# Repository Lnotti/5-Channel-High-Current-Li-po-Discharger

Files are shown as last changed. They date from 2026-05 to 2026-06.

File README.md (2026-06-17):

# 5 Channel High Current LiPo Storage Discharger

A PCB designed to discharge 6S LiHV battery packs to storage voltage (3.8V per cell / 22.8V total) across up to 5 independent channels simultaneously.

## Overview

Leaving LiPo packs fully charged for extended periods degrades cell chemistry over time. This board solves that by providing a dedicated, controlled way to bring packs down to storage voltage after a flying session without needing a full featured charger to do it.

Each of the 5 channels accepts a 6S pack via an XT60 connector and independently discharges it to 22.8V, cutting off automatically when the target is reached. Channels are fully isolated from each other so packs at different voltages can be discharged simultaneously without risk.

## Problems with current solutions

I have a lipo charger that doubles as a lipo discharger, but it falls short in many aspects.
- Cost ($100+)
- Only two channels
- Discharge current only 0.2A max
- Slows down immensely close to the end of discharge cycle

I also have small lipo discharger that clip onto individual packs that also fall short
- Takes 3+ hours to discharge to storage
- Only has a light to let me know that it has finished (I forget about them since they are so small)
- High leakage current
- High leakage current combined with the time taken to discharge combined with their forgettability leads to frequent overdischarging making me plug them back in to charge ruining the ease

## Status

Version 0.1.1 is a complete board redesign addressing multiple hardware issues identified during review of the 0.1.0 prototype. The revised board has been submitted for manufacture. Testing and firmware development are ongoing.

## Hardware

- STM32F103C8T6 microcontroller
- Active MOSFET load per channel with wirewound power resistors
- Buck converter and 3.3V LDO onboard power supply
- USB-C port for firmware flashing via DFU bootloader
- Active cooling via 40mm 5V fan
- Power status LED for supply rail debugging
- SWD header for live debugging
- Multiple STM32 connectivity options: USB, I2C, ST-Link, UART, DFU

## Specifications

- Input: 6S LiHV (22.8V - 26.1V)
- Channels: 5 independent
- Discharge current: approximately 1A per channel
- Target storage voltage: 22.8V (3.8V per cell)
- Connector: XT60 female PCB mount
- Board dimensions: 160 x 110mm

## Version History

### v0.1.1 — Complete Board Redesign
*Current version*

A full redesign addressing hardware errors found during schematic and layout review of v0.1.0.

**Bug fixes:**
- Corrected footprints for large wirewound power resistors which were wrong in v0.1.0
- Fixed STM32F103C8T6 footprint which was incorrect in v0.1.0
- Replaced buck converter with a higher rated part after identifying that the original selection would be insufficient for LiHV pack voltages (26.1V max vs 25.2V assumed for standard LiPo)
- Updated voltage divider resistor values (1M / 120k) to bring the ADC sense voltage within safe range for LiHV full charge voltage — previous values would have exceeded the STM32 3.3V ADC input limit at 26.1V
- Updated voltage dividers to higher values to reduce current draw, as to not discharge batteries less than their storage voltage after discharging process is complete.

**Design changes:**
- Discharge resistors repositioned to the center of the board based on thermal simulation results for improved heat distribution
- Removed per-channel RGB LEDs to simplify bring-up and reduce scope; power system debugging is now the immediate priority
- Added power rail status LED to aid debugging of the onboard supply
- Added multiple STM32 connectivity options: USB, I2C, ST-Link, UART, DFU headers
- Removed oversized battery net traces; 1A continuous current does not require large copper pours
- Redesigned discharge channels using hierarchical sheets for layout uniformity across all 5 channels and easier future edits
- General board layout cleanup and component alignment

**Known limitations:**
- RGB per-channel status LEDs removed; may be reintroduced in a later revision once core functionality is validated
- Unsure of how precise the mosfet discharge current in relation to gate voltage will be, this may create issues with precision at the end of a discharge cycle limiting speed.
- Firmware development not yet started
- Unsure of what control loop I will use to handle getting to storage voltage at a consistent current with no overshoot

---

### v0.1.0 — Initial Prototype
*First PCB submission. Multiple hardware errors identified prior to and during bring-up.*

- Initial 5-channel discharge board design
- STM32F103C8T6 microcontroller
- PCA9685 16 channel PWM driver for RGB status LEDs
- Per channel RGB status LED
- USB-C DFU bootloader
- SWD debug header
- 160 x 110mm board

**Issues identified:**
- Wrong footprints for wirewound power resistors
- Wrong STM32 footprint
- Buck converter underrated for LiHV input voltage
- Voltage divider ratio unsafe for LiHV full charge voltage on STM32 ADC
- Board layout not uniform across discharge channels

---

## Planned Revisions

- Case design with integrated fan mounting and ventilation
- Thermal testing and validation on physical hardware
- Firmware development and testing
- Potential reintroduction of per-channel RGB status LEDs
- Potential support for additional cell counts
- Further refinement based on prototype testing results

## Repository Contents

- KiCad schematic and PCB layout files
- Gerber files for manufacture
- Bill of materials

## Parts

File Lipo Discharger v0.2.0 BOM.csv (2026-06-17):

Id | Designator | Footprint | Quantity | Designation | Supplier and ref
1 | C1 | C_0805_2012Metric_Pad1.18x1.45mm_HandSolder | 1 | 10uf 35V
2 | C2, C18, C19, C20, C21, C22 | C_0805_2012Metric_Pad1.18x1.45mm_HandSolder | 6 | 100nF
3 | C3, C4, C6 | C_0805_2012Metric_Pad1.18x1.45mm_HandSolder | 3 | 22µF
4 | C5 | C_0805_2012Metric_Pad1.18x1.45mm_HandSolder | 1 | 10µF
5 | C7 | C_0603_1608Metric | 1 | 10u
6 | C8, C9, C10, C11, C12 | C_0402_1005Metric | 5 | 100n
7 | C13 | C_0402_1005Metric | 1 | 10n
8 | C14, C15 | C_0402_1005Metric | 2 | 1u
9 | C17, C25 | C_0402_1005Metric | 2 | 10p
10 | D1 | D_SMB_Handsoldering | 1 | SS34
11 | D3, D4, D5, D6, D7 | D_SMB_Handsoldering | 5 | SMBJ26A
12 | D13 | D_DO-35_SOD27_P7.62mm_Horizontal | 1 | 1N4148
13 | D14, D15, D16, D17, D18 | D_SMA | 5 | SS34
14 | D19 | LED_2010_5025Metric_Pad1.52x2.65mm_HandSolder | 1 | LED
15 | FAN | PinHeader_1x02_P2.54mm_Vertical | 1 | FAN
16 | FB1 | L_0603_1608Metric | 1 | 120R
17 | I2C, ST-Link, UART | PinHeader_1x04_P2.00mm_Vertical | 3 | Conn_01x04_Male
18 | J2 | USB_C_Receptacle_HRO_TYPE-C-31-M-12 | 1 | USB_C_Receptacle_USB2.0_16P
19 | J4, J5, J6, J7, J8 | AMASS_XT60PW-M_1x02_P7.20mm_Horizontal | 5 | XT60_P1
20 | L1 | L_7.3x7.3_H4.5 | 1 | 4.7µH
21 | Q1, Q2, Q3, Q4, Q5 | TO-220-3_Vertical | 5 | IRLZ44N
22 | Q6 | TO-92_Inline | 1 | 2N2222
23 | R2 | R_0402_1005Metric | 1 | 10k
24 | R3 | R_0402_1005Metric | 1 | 1k5
25 | R4 | R_0805_2012Metric_Pad1.20x1.40mm_HandSolder | 1 | 1K
26 | R8, R14, R20, R26, R32 | R_0805_2012Metric_Pad1.20x1.40mm_HandSolder | 5 | 1M
27 | R9, R15, R21, R27, R33 | R_0805_2012Metric_Pad1.20x1.40mm_HandSolder | 5 | 120k
28 | R10, R17, R23, R29, R35 | R_0805_2012Metric_Pad1.20x1.40mm_HandSolder | 5 | 10
29 | R11, R16, R22, R28, R34 | R_0805_2012Metric_Pad1.20x1.40mm_HandSolder | 5 | 100k
30 | R12, R13, R18, R19, R24, R25, R30, R31, R36, R37, R55, R56, R57, R58, R59 | R_Axial_Power_L38.0mm_W6.4mm_P45.72mm | 15 | 8.2R 10W
31 | R54 | R_0805_2012Metric_Pad1.20x1.40mm_HandSolder | 1 | 100
32 | RP_SCL1, RP_SDA1 | R_0402_1005Metric | 2 | 2k2
33 | SW1 | SW_PUSH_6mm | 1 | SW_Push
34 | U1 | TSOT-23-6 | 1 | AP63205WU-7
35 | U2 | SOT-223-3_TabPin2 | 1 | AMS1117-3.3
36 | U3 | LQFP-48_7x7mm_P0.5mm | 1 | STM32F103C8T6
37 | Y1 | Crystal_SMD_3225-4Pin_3.2x2.5mm | 1 | 16MHz

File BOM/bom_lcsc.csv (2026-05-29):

Id | Designator | Footprint | Quantity | Designation
1 | C1 | C_0805_2012Metric | 1 | 10uF 35V
2 | C2,C7,C8,C9,C10,C11,C12,C15,C18,C19,C20,C21,C22,C23 | C_0805_2012Metric | 14 | 100nF
3 | C3,C4 | C_0805_2012Metric | 2 | 22uF 10V
4 | C5,C6 | C_0805_2012Metric | 2 | 10uF
5 | C13 | C_0805_2012Metric | 1 | 1uF
6 | C14 | C_0805_2012Metric | 1 | 10nF
7 | C16,C17 | C_0805_2012Metric | 2 | 20pF
8 | D1 | D_SMB | 1 | SMBJ26A
9 | D2 | D_SMB | 1 | SS34
10 | D3,D5,D7,D9,D11 | D_SMB | 5 | SMBJ26A
11 | D4,D6,D8,D10,D12 | LED_D5.0mm_RGB | 5 | RGB LED Common Cathode 5mm
12 | D13 | D_DO-35 | 1 | 1N4148
13 | D14,D15,D16,D17,D18 | D_SMA | 5 | SS34
14 | F1 | Fuse_1206 | 1 | Polyfuse 500mA
15 | J2 | USB_C_Receptacle | 1 | USB-C Receptacle 16P
16 | J3 | PinHeader_1x04_P2.54mm | 1 | Pin Header 1x4 2.54mm
17 | J4,J5,J6,J7,J8 | AMASS_XT60-F | 5 | XT60 Female PCB Mount
18 | J9 | PinHeader_1x02_P2.54mm | 1 | Pin Header 1x2 2.54mm
19 | L1 | L_Bourns_SRR1260 | 1 | 22uH SRR1260
20 | Q1,Q2,Q3,Q4,Q5 | TO-220-3 | 5 | IRLZ44NPBF
21 | Q6 | TO-92 | 1 | 2N2222
22 | R1,R8,R11,R14,R16,R20,R22,R26,R28,R32,R34 | R_0805 | 11 | 100k 1%
23 | R2 | R_0805 | 1 | 20k 1%
24 | R3,R4,R48 | R_0805 | 3 | 10k
25 | R5 | R_0805 | 1 | 1M
26 | R6,R7 | R_0805 | 2 | 5.1k
27 | R9,R15,R21,R27,R33 | R_0805 | 5 | 15k 1%
28 | R10,R17,R23,R29,R35 | R_0805 | 5 | 10R
29 | R12,R13,R18,R19,R24,R25,R30,R31,R36,R37,R55,R56,R57,R58,R59 | R_Axial_Power | 15 | 8.2R 10W
30 | R38,R41,R44,R47,R51 | R_0805 | 5 | 68R
31 | R39,R40,R42,R43,R45,R46,R49,R50,R52,R53 | R_0805 | 10 | 22R
32 | R54 | R_0805 | 1 | 100R
33 | SW1 | SW_PUSH_6mm | 1 | Tactile Switch 6mm
34 | U1 | TSOT-23-6 | 1 | MP2359DJ-LF-Z
35 | U2 | SOT-223-3 | 1 | AMS1117-3.3
36 | U3 | LQFP-48 | 1 | STM32F103C8T6
37 | U4 | QFN-28 | 1 | PCA9685BS
38 | Y1 | Crystal_SMD_3225-4Pin | 1 | 8MHz Crystal

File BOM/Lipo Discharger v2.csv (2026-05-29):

Id | Designator | Footprint | Quantity | Designation | Supplier and ref
1 | C1 | C_0805_2012Metric_Pad1.18x1.45mm_HandSolder | 1 | 10uf 35V
2 | C2, C7, C8, C9, C10, C11, C12, C15, C18, C19, C20, C21, C22, C23 | C_0805_2012Metric_Pad1.18x1.45mm_HandSolder | 14 | 100nF
3 | C3, C4 | C_0805_2012Metric_Pad1.18x1.45mm_HandSolder | 2 | 22uF 10V
4 | C5, C6 | C_0805_2012Metric_Pad1.18x1.45mm_HandSolder | 2 | 10uF
5 | C13 | C_0805_2012Metric_Pad1.18x1.45mm_HandSolder | 1 | 1uF
6 | C14 | C_0805_2012Metric_Pad1.18x1.45mm_HandSolder | 1 | 10nF
7 | C16, C17 | C_0805_2012Metric_Pad1.18x1.45mm_HandSolder | 2 | 20pF
8 | D1 | D_SMB_Handsoldering | 1 | D_TVS
9 | D2 | D_SMB_Handsoldering | 1 | SS34
10 | D3, D5, D7, D9, D11 | D_SMB_Handsoldering | 5 | SMBJ26A
11 | D4, D6, D8, D10, D12 | LED_D5.0mm-4_RGB | 5 | LED_KRGB
12 | D13 | D_DO-35_SOD27_P7.62mm_Horizontal | 1 | 1N4148
13 | D14, D15, D16, D17, D18 | D_SMA | 5 | SS34
14 | F1 | Fuse_1206_3216Metric_Pad1.42x1.75mm_HandSolder | 1 | Polyfuse
15 | J2 | USB_C_Receptacle_HRO_TYPE-C-31-M-12 | 1 | USB_C_Receptacle_USB2.0_16P
16 | J3 | PinHeader_1x04_P2.54mm_Vertical | 1 | SWD
17 | J4 | AMASS_XT60-F_1x02_P7.20mm_Vertical | 1 | XT60_P1
18 | J5 | AMASS_XT60-F_1x02_P7.20mm_Vertical | 1 | XT60_P2
19 | J6 | AMASS_XT60-F_1x02_P7.20mm_Vertical | 1 | XT60_P3
20 | J7 | AMASS_XT60-F_1x02_P7.20mm_Vertical | 1 | XT60_P4
21 | J8 | AMASS_XT60-F_1x02_P7.20mm_Vertical | 1 | XT60_P5
22 | J9 | PinHeader_1x02_P2.54mm_Vertical | 1 | FAN
23 | L1 | L_Bourns_SRR1260 | 1 | 22uH
24 | Q1, Q2, Q3, Q4, Q5 | TO-220-3_Vertical | 5 | IRLZ44N
25 | Q6 | TO-92_Inline | 1 | 2N2222
26 | R1, R8, R11, R14, R16, R20, R22, R26, R28, R32, R34 | R_0805_2012Metric_Pad1.20x1.40mm_HandSolder | 11 | 100k
27 | R2 | R_0805_2012Metric_Pad1.20x1.40mm_HandSolder | 1 | 20k
28 | R3, R4, R48 | R_0805_2012Metric_Pad1.20x1.40mm_HandSolder | 3 | 10k
29 | R5 | R_0805_2012Metric_Pad1.20x1.40mm_HandSolder | 1 | 1M
30 | R6, R7 | R_0805_2012Metric_Pad1.20x1.40mm_HandSolder | 2 | 5.1k
31 | R9, R15, R21, R27, R33 | R_0805_2012Metric_Pad1.20x1.40mm_HandSolder | 5 | 15k
32 | R10, R17, R23, R29, R35 | R_0805_2012Metric_Pad1.20x1.40mm_HandSolder | 5 | 10
33 | R12, R13, R18, R19, R24, R25, R30, R31, R36, R37, R55, R56, R57, R58, R59 | R_Axial_Power_L25.0mm_W9.0mm_P27.94mm | 15 | 8.2R 10W
34 | R38, R41, R44, R47, R51 | R_0805_2012Metric_Pad1.20x1.40mm_HandSolder | 5 | 68
35 | R39, R40, R42, R43, R45, R46, R49, R50, R52, R53 | R_0805_2012Metric_Pad1.20x1.40mm_HandSolder | 10 | 22
36 | R54 | R_0805_2012Metric_Pad1.20x1.40mm_HandSolder | 1 | 100
37 | SW1 | SW_PUSH_6mm | 1 | BOOT0_BTN
38 | U1 | TSOT-23-6_HandSoldering | 1 | MP2359DJ-LF-Z
39 | U2 | SOT-223-3_TabPin2 | 1 | AMS1117-3.3
40 | U3 | LQFP-48_7x7mm_P0.5mm | 1 | STM32F103C8Tx
41 | U4 | TSSOP-28_4.4x9.7mm_P0.65mm | 1 | PCA9685BS
42 | Y1 | Crystal_SMD_3225-4Pin_3.2x2.5mm_HandSoldering | 1 | 8MHz

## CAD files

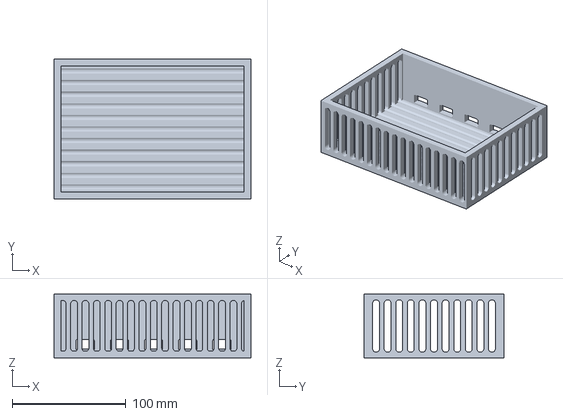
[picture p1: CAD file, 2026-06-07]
Solidworks/Base^Case_AssemblyV1.0.0.3mf
173.0 x 123.0 x 56.0 mm

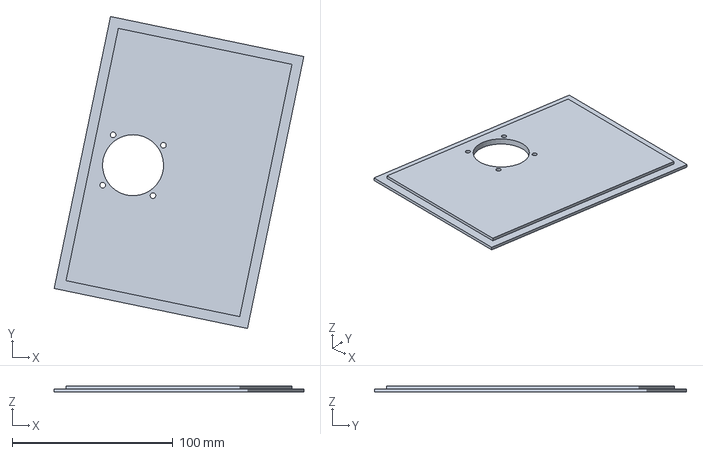
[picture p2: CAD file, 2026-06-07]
Solidworks/Lid^Case_AssemblyV1.0.0.3mf
155.5 x 194.4 x 4.00 mm

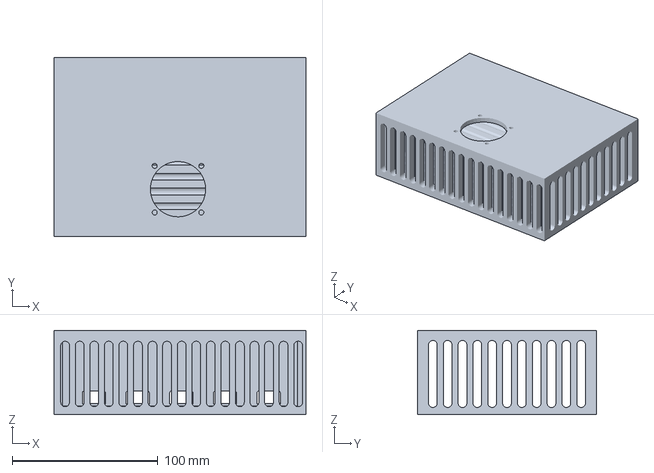
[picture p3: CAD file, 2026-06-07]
Solidworks/Case^AssemblyV1.0.0.3MF
173.0 x 123.0 x 58.0 mm

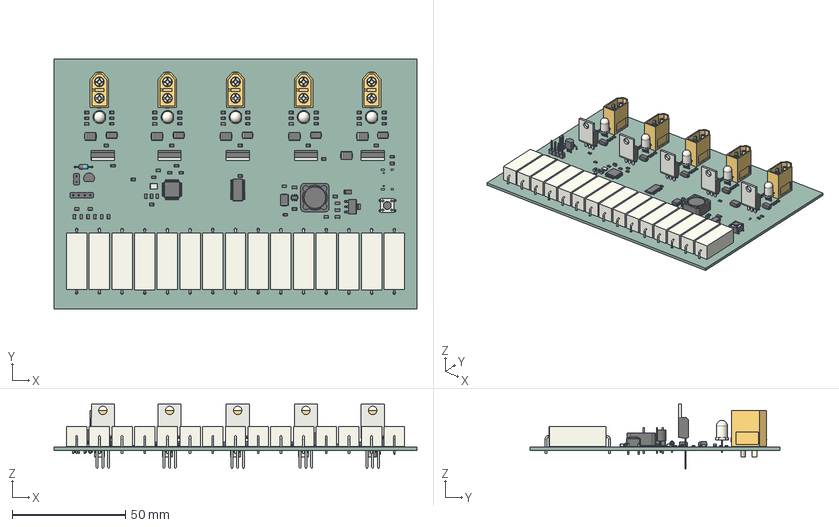
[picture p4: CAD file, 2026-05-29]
_restore_backup_2026-05-21T22-28-28-728/Lipo Discharger.step
160.0 x 110.0 x 28.5 mm
C_0805_2012Metric x 23
XT60 male v9 x 5
R_Axial_Power_L250mm_W90mm_P2794mm x 15
LED_D5.0mm-4 x 5
R_0805_2012Metric x 44
D_SMB x 7
D_SMA x 5
SOT-223
TO-220-3_Vertical x 5
SW_PUSH_6mm
TO-92_Inline_Narrow
Crystal_SMD_3225-4Pin_3.2x2.5mm
PinHeader_1x04_P254mm_Vertical
LQFP-48_7x7mm_P0.5mm
Fuse_1206_3216Metric
SRR1260
TSOT-23-6
TSSOP-28_4.4x9.7mm_P0.65mm
D_DO-35_SOD27_P7.62mm_Horizontal
PinHeader_1x02_P254mm_Vertical
Lipo Discharger_PCB

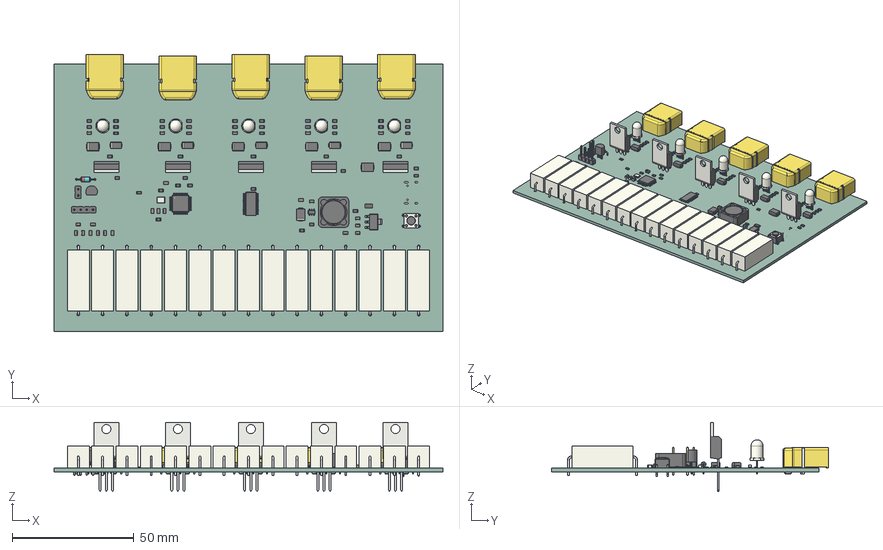
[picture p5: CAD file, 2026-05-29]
_restore_backup_2026-05-21T22-28-28-728/BoardV2.step
160.0 x 113.8 x 28.5 mm
C_0805_2012Metric x 23
XT60PW-M x 5
R_Axial_Power_L250mm_W90mm_P2794mm x 15
LED_D5.0mm-4 x 5
R_0805_2012Metric x 44
D_SMB x 7
D_SMA x 5
SOT-223
TO-220-3_Vertical x 5
SW_PUSH_6mm
TO-92_Inline_Narrow
Crystal_SMD_3225-4Pin_3.2x2.5mm
PinHeader_1x04_P254mm_Vertical
LQFP-48_7x7mm_P0.5mm
Fuse_1206_3216Metric
SRR1260
TSOT-23-6
TSSOP-28_4.4x9.7mm_P0.65mm
D_DO-35_SOD27_P7.62mm_Horizontal
PinHeader_1x02_P254mm_Vertical
Lipo Discharger_PCB

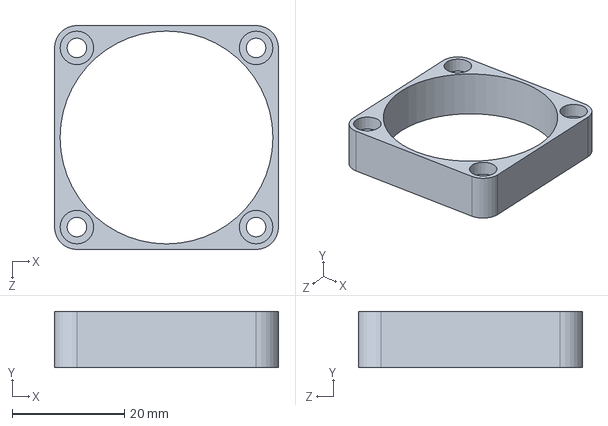
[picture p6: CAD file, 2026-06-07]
Solidworks/Fan_ModelV1.SLDPRT
40.0 x 10.0 x 40.0 mm

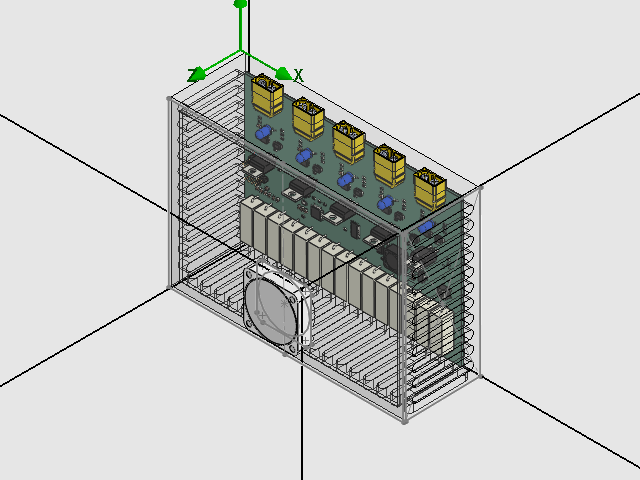
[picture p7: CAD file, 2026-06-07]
Solidworks/AssemblyV1.0.0.SLDASM
C_0805_2012Metric-0_1.step x 23
XT60PW-M-1_1.step x 5
R_Axial_Power_L250mm_W90mm_P2794mm_1.step x 15
LED_D5.0mm-4_RGB_Wide_Pins-2_1.step x 5
R_0805_2012Metric-3_1.step x 44
D_SMB-4_1.step x 7
D_SMA-5_1.step x 5
SOT-223-6_1.step
TO-220-3_Vertical-7_1.step x 5
SW_PUSH_6mm-8_1.step
TO-92_Inline_Narrow_1.step
Crystal_SMD_3225-4Pin_3.2x2.5mm-9_1.step
PinHeader_1x04_P254mm_Vertical_1.step
LQFP-48_7x7mm_P0.5mm-10_1.step
Fuse_1206_3216Metric-11_1.step
SRR1260_1.step
TSOT-23-6-12_1.step
TSSOP-28_4.4x9.7mm_P0.65mm-13_1.step
D_DO-35_SOD27_P7.62mm_Horizontal-14_1.step
PinHeader_1x02_P254mm_Vertical_1.step
Lipo Discharger_PCB_1.step
Copy of Part44^Case_AssemblyV1.0.0
Lid^Case_AssemblyV1.0.0
Fan_ModelV1
LID17
LID18
LID19
LID20
LID21

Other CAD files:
Solidworks/CaseV1.0.0.SLDASM
Solidworks/BoardV4.step.SLDASM
Solidworks/LID13.SLDPRT
Solidworks/LID15.SLDPRT
Solidworks/LID4.SLDPRT
Solidworks/LID3.SLDPRT
Solidworks/LID14.SLDPRT
Solidworks/LID19.SLDPRT
Solidworks/LID17.SLDPRT
Solidworks/LID7.SLDPRT
Solidworks/AssemblyV1.0.0.3mf
Solidworks/BoardV1.0.0.step
Solidworks/BoardV3.step
Solidworks/BoardV4.SLDASM
Solidworks/BoardV4.step
Solidworks/CaseV1.0.0.3mf
Solidworks/CaseV1.0.SLDPRT
Solidworks/LID1.SLDPRT
Solidworks/LID10.SLDPRT
Solidworks/LID11.SLDPRT
Solidworks/LID12.SLDPRT
Solidworks/LID16.SLDPRT
Solidworks/LID18.SLDPRT
Solidworks/LID2.SLDPRT
Solidworks/LID20.SLDPRT
Solidworks/LID21.SLDPRT
Solidworks/LID5.SLDPRT
Solidworks/LID6.SLDPRT
Solidworks/LID8.SLDPRT
Solidworks/LID9.SLDPRT
Solidworks/Lipo Discharger.SLDASM
_restore_backup_2026-05-21T22-28-28-728/Lipo Discharger.SLDASM
_restore_backup_2026-05-21T22-44-01-964/Lipo Discharger.SLDASM

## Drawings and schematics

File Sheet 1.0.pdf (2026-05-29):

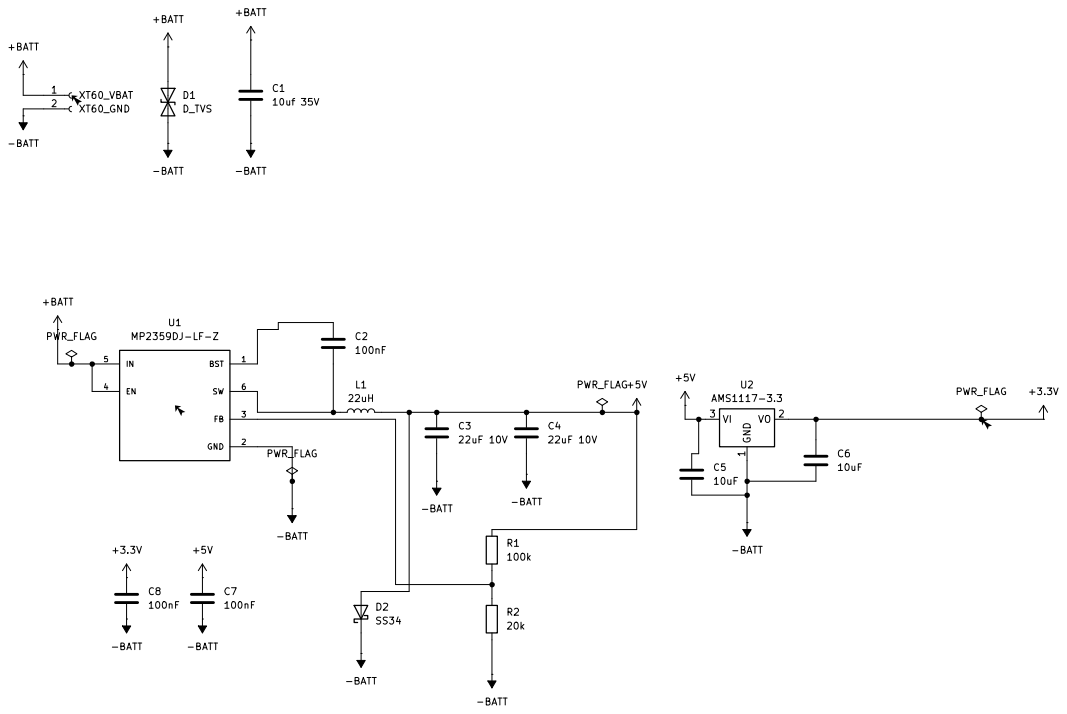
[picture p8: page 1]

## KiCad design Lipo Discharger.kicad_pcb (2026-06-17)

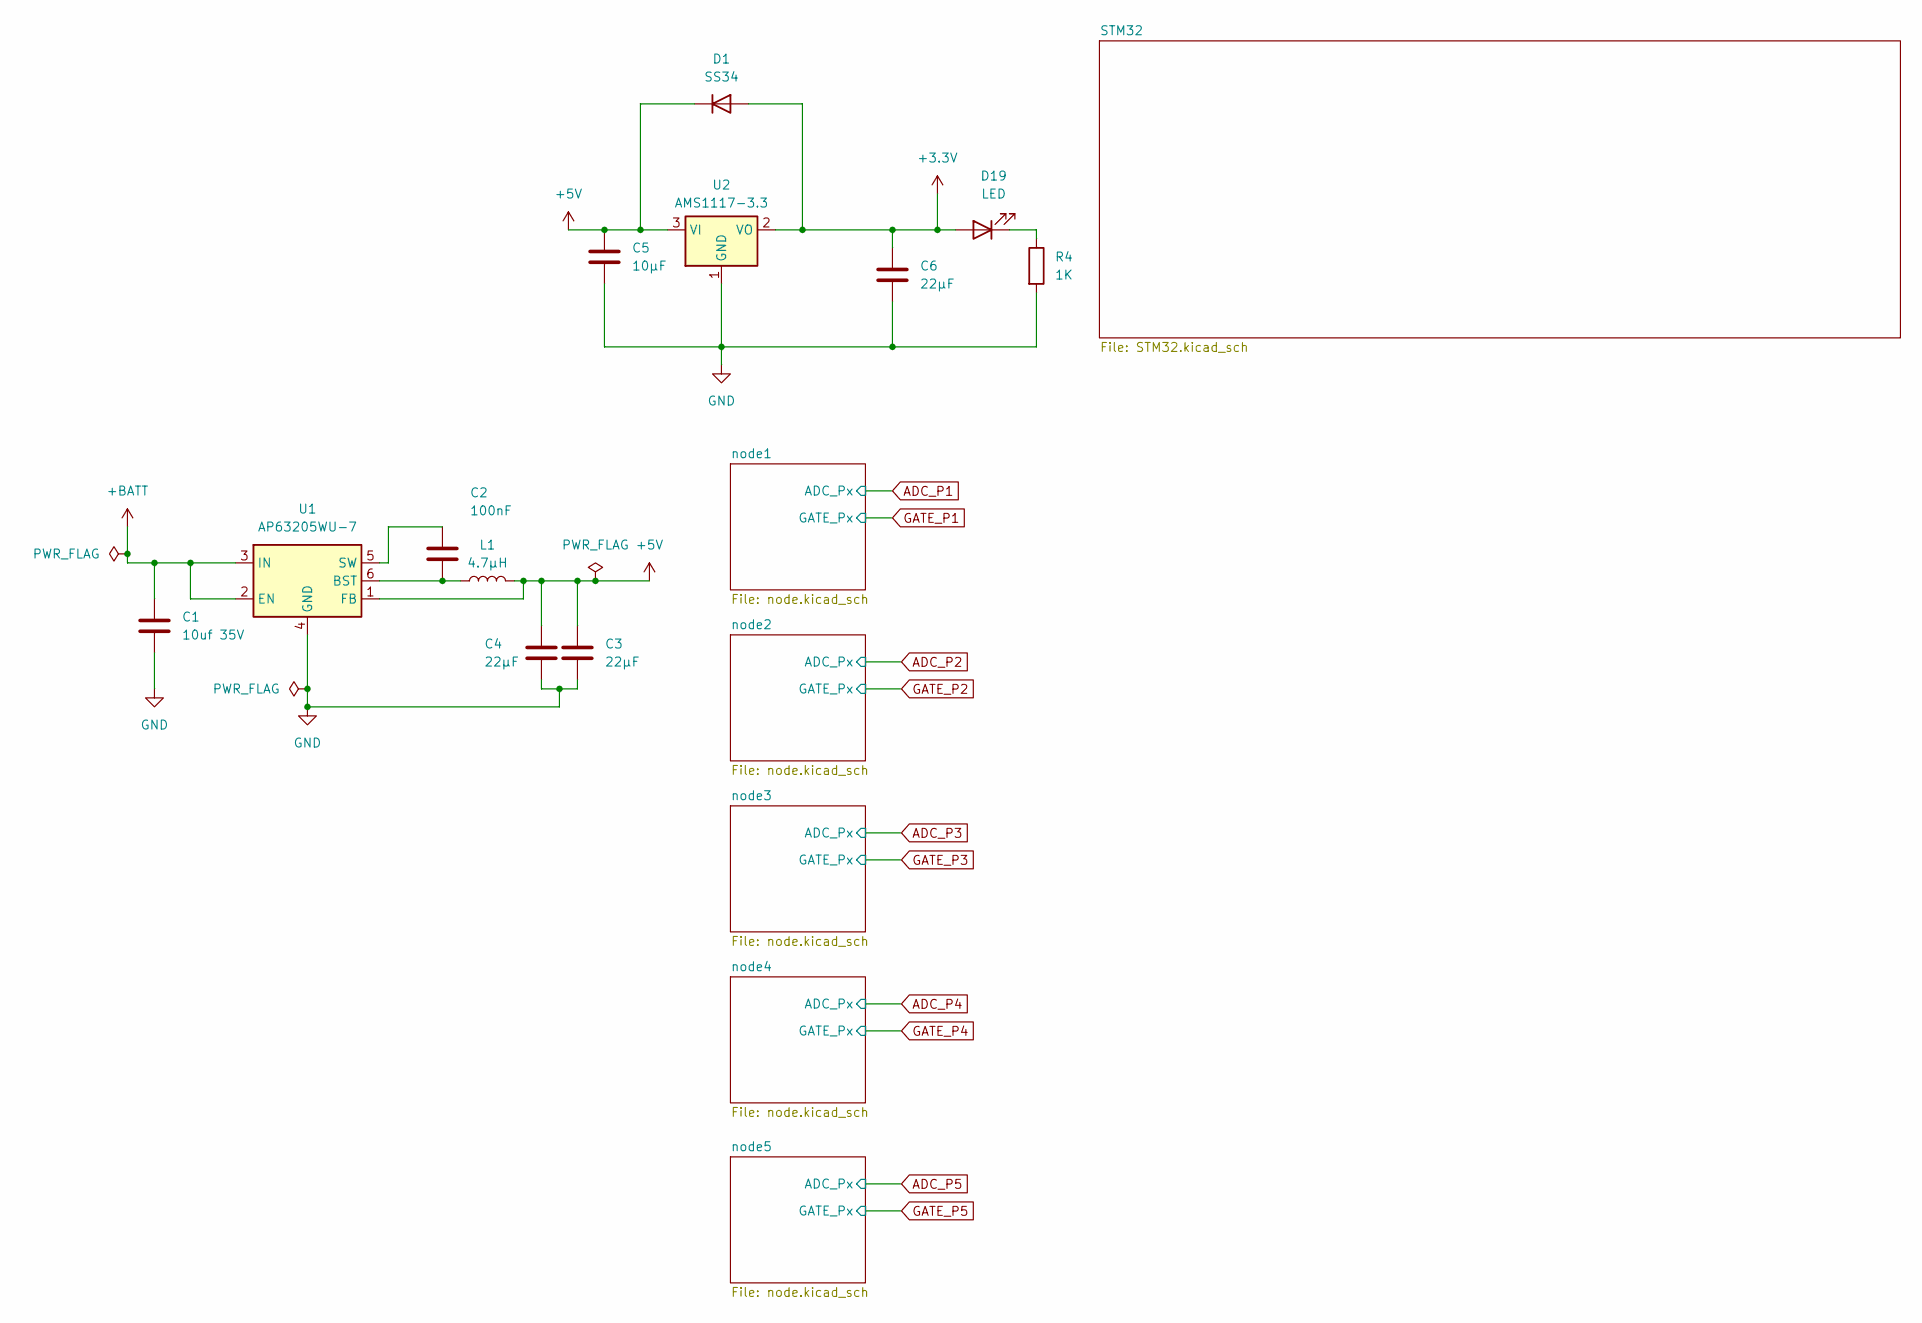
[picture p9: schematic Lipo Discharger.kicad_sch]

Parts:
C1: 10uf 35V; C_0805_2012Metric_Pad1.18x1.45mm_HandSolder
C2: 100nF; C_0805_2012Metric_Pad1.18x1.45mm_HandSolder
C3, C4, C6: 22µF; C_0805_2012Metric_Pad1.18x1.45mm_HandSolder
C5: 10µF; C_0805_2012Metric_Pad1.18x1.45mm_HandSolder
D1: SS34; D_SMB_Handsoldering
D19: LED; LED_2010_5025Metric_Pad1.52x2.65mm_HandSolder
L1: 4.7µH; L_7.3x7.3_H4.5
R4: 1K; R_0805_2012Metric_Pad1.20x1.40mm_HandSolder
U1: AP63205WU-7; TSOT-23-6
U2: AMS1117-3.3; SOT-223-3_TabPin2

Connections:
+3.3V: C6.1, D1.2 (A), D19.2 (A), U2.2 (VO); also elsewhere on the board
+5V: C3.1, C4.1, C5.1, D1.1 (K), L1.2, U1.1 (FB), U2.3 (VI); also elsewhere on the board
+BATT: C1.1, U1.2 (EN), U1.3 (IN); also elsewhere on the board
GND: C1.2, C3.2, C4.2, C5.2, C6.2, R4.2, U1.4 (GND), U2.1 (GND); also elsewhere on the board
unnamed: D19.1 (K), R4.1
unnamed: C2.2, L1.1, U1.6 (BST)
unnamed: C2.1, U1.5 (SW)

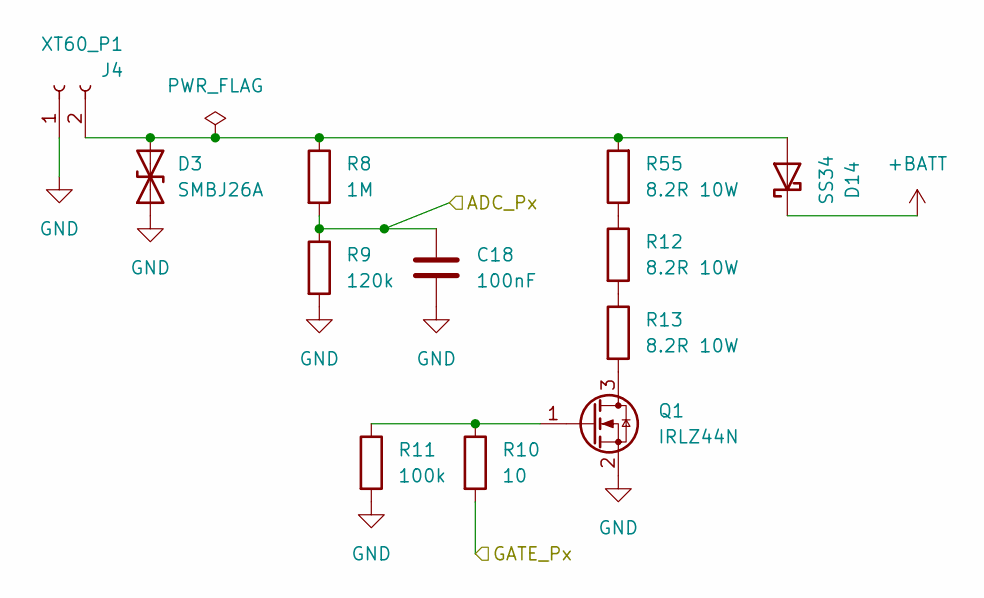
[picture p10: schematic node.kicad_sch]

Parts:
C18: 100nF; C_0805_2012Metric_Pad1.18x1.45mm_HandSolder
D3: SMBJ26A; D_SMB_Handsoldering
D14: SS34; D_SMA
J4: XT60_P1; AMASS_XT60PW-M_1x02_P7.20mm_Horizontal
Q1: IRLZ44N; TO-220-3_Vertical
R8: 1M; R_0805_2012Metric_Pad1.20x1.40mm_HandSolder
R9: 120k; R_0805_2012Metric_Pad1.20x1.40mm_HandSolder
R10: 10; R_0805_2012Metric_Pad1.20x1.40mm_HandSolder
R11: 100k; R_0805_2012Metric_Pad1.20x1.40mm_HandSolder
R12, R13, R55: 8.2R 10W; R_Axial_Power_L38.0mm_W6.4mm_P45.72mm

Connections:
+BATT: D14.1 (K); also elsewhere on the board
ADC_P1: C18.1, R8.2, R9.1; also elsewhere on the board
GATE_P1: R10.2; also elsewhere on the board
GND: C18.2, D3.1 (A1), J4.1, Q1.2 (S), R9.2, R11.2; also elsewhere on the board
unnamed: D3.2 (A2), D14.2 (A), J4.2, R8.1, R55.2
unnamed: Q1.3 (D), R13.2
unnamed: Q1.1 (G), R10.1, R11.1
unnamed: R12.1, R55.1
unnamed: R12.2, R13.1

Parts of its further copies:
C19, C20, C21, C22: 100nF; C_0805_2012Metric_Pad1.18x1.45mm_HandSolder
D4, D5, D6, D7: SMBJ26A; D_SMB_Handsoldering
D15, D16, D17, D18: SS34; D_SMA
J5, J6, J7, J8: XT60_P1; AMASS_XT60PW-M_1x02_P7.20mm_Horizontal
Q2, Q3, Q4, Q5: IRLZ44N; TO-220-3_Vertical
R14, R20, R26, R32: 1M; R_0805_2012Metric_Pad1.20x1.40mm_HandSolder
R15, R21, R27, R33: 120k; R_0805_2012Metric_Pad1.20x1.40mm_HandSolder
R16, R22, R28, R34: 100k; R_0805_2012Metric_Pad1.20x1.40mm_HandSolder
R17, R23, R29, R35: 10; R_0805_2012Metric_Pad1.20x1.40mm_HandSolder
R18, R19, R24, R25, R30, R31, R36, R37, R56, R57, R58, R59: 8.2R 10W; R_Axial_Power_L38.0mm_W6.4mm_P45.72mm

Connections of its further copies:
+BATT: D15.1 (K), D16.1 (K), D17.1 (K), D18.1 (K); also elsewhere on the board
ADC_P2: C19.1, R14.2, R15.1; also elsewhere on the board
ADC_P3: C20.1, R20.2, R21.1; also elsewhere on the board
ADC_P4: C21.1, R26.2, R27.1; also elsewhere on the board
ADC_P5: C22.1, R32.2, R33.1; also elsewhere on the board
GATE_P2: R17.2; also elsewhere on the board
GATE_P3: R23.2; also elsewhere on the board
GATE_P4: R29.2; also elsewhere on the board
GATE_P5: R35.2; also elsewhere on the board
GND: C19.2, C20.2, C21.2, C22.2, D4.1 (A1), D5.1 (A1), D6.1 (A1), D7.1 (A1), J5.1, J6.1, J7.1, J8.1, Q2.2 (S), Q3.2 (S), Q4.2 (S), Q5.2 (S), R15.2, R16.2, R21.2, R22.2, R27.2, R28.2, R33.2, R34.2; also elsewhere on the board
unnamed: D4.2 (A2), D15.2 (A), J5.2, R14.1, R56.2
unnamed: D5.2 (A2), D16.2 (A), J6.2, R20.1, R57.2
unnamed: D6.2 (A2), D17.2 (A), J7.2, R26.1, R58.2
unnamed: D7.2 (A2), D18.2 (A), J8.2, R32.1, R59.2
unnamed: Q2.3 (D), R19.2
unnamed: Q2.1 (G), R16.1, R17.1
unnamed: Q3.3 (D), R25.2
unnamed: Q3.1 (G), R22.1, R23.1
unnamed: Q4.3 (D), R31.2
unnamed: Q4.1 (G), R28.1, R29.1
unnamed: Q5.3 (D), R37.2
unnamed: Q5.1 (G), R34.1, R35.1
unnamed: R18.1, R56.1
unnamed: R18.2, R19.1
unnamed: R24.1, R57.1
unnamed: R24.2, R25.1
unnamed: R30.1, R58.1
unnamed: R30.2, R31.1
unnamed: R36.1, R59.1
unnamed: R36.2, R37.1

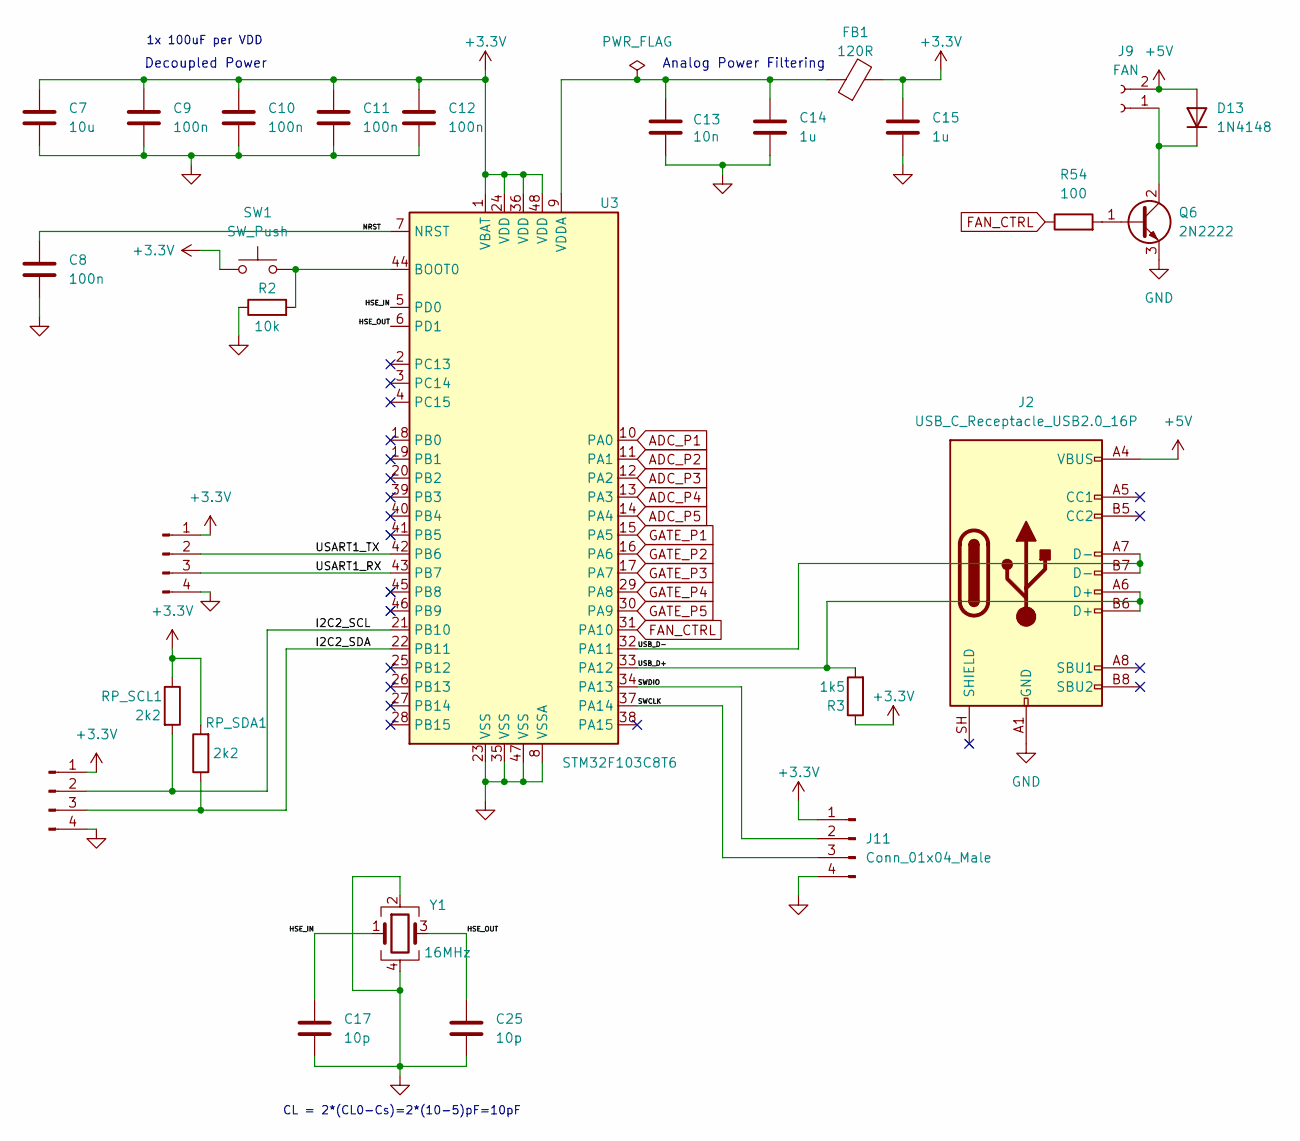
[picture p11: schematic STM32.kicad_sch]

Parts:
C7: 10u; C_0603_1608Metric
C8, C9, C10, C11, C12: 100n; C_0402_1005Metric
C13: 10n; C_0402_1005Metric
C14, C15: 1u; C_0402_1005Metric
C17, C25: 10p; C_0402_1005Metric
D13: 1N4148; D_DO-35_SOD27_P7.62mm_Horizontal
FB1: 120R; L_0603_1608Metric
J1, J3, J11: Conn_01x04_Male; PinHeader_1x04_P2.00mm_Vertical
J2: USB_C_Receptacle_USB2.0_16P; USB_C_Receptacle_HRO_TYPE-C-31-M-12
J9: FAN; PinHeader_1x02_P2.54mm_Vertical
Q6: 2N2222; TO-92_Inline
R2: 10k; R_0402_1005Metric
R3: 1k5; R_0402_1005Metric
R54: 100; R_0805_2012Metric_Pad1.20x1.40mm_HandSolder
RP_SCL1: 2k2; R_0402_1005Metric
RP_SDA1: 2k2; R_0402_1005Metric
SW1: SW_Push; SW_PUSH_6mm
U3: STM32F103C8T6; LQFP-48_7x7mm_P0.5mm
Y1: 16MHz; Crystal_SMD_3225-4Pin_3.2x2.5mm

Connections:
+3.3V: C7.1, C9.1, C10.1, C11.1, C12.1, C15.1, FB1.2, J1.1, J3.1, J11.1, R3.1, RP_SCL1.1, RP_SDA1.2, SW1.1, U3.1 (VBAT), U3.24 (VDD), U3.36 (VDD), U3.48 (VDD); also elsewhere on the board
+5V: D13.2 (A), J2.A4 (VBUS), J2.A9 (VBUS), J2.B4 (VBUS), J2.B9 (VBUS), J9.2; also elsewhere on the board
/STM32/HSE_IN: C17.1, U3.5 (PD0), Y1.1
/STM32/HSE_OUT: C25.1, U3.6 (PD1), Y1.3
/STM32/I2C2_SCL: J3.2, RP_SCL1.2, U3.21 (PB10); also elsewhere on the board
/STM32/I2C2_SDA: J3.3, RP_SDA1.1, U3.22 (PB11); also elsewhere on the board
/STM32/NRST: C8.1, U3.7 (NRST)
/STM32/SWCLK: J11.3, U3.37 (PA14); also elsewhere on the board
/STM32/SWDIO: J11.2, U3.34 (PA13); also elsewhere on the board
/STM32/USART1_RX: J1.3, U3.43 (PB7); also elsewhere on the board
/STM32/USART1_TX: J1.2, U3.42 (PB6); also elsewhere on the board
/STM32/USB_D+: J2.A6 (D+), J2.B6 (D+), R3.2, U3.33 (PA12)
/STM32/USB_D-: J2.A7 (D-), J2.B7 (D-), U3.32 (PA11)
ADC_P1: U3.10 (PA0); also elsewhere on the board
ADC_P2: U3.11 (PA1); also elsewhere on the board
ADC_P3: U3.12 (PA2); also elsewhere on the board
ADC_P4: U3.13 (PA3); also elsewhere on the board
ADC_P5: U3.14 (PA4); also elsewhere on the board
FAN_CTRL: R54.1, U3.31 (PA10)
GATE_P1: U3.15 (PA5); also elsewhere on the board
GATE_P2: U3.16 (PA6); also elsewhere on the board
GATE_P3: U3.17 (PA7); also elsewhere on the board
GATE_P4: U3.29 (PA8); also elsewhere on the board
GATE_P5: U3.30 (PA9); also elsewhere on the board
GND: C7.2, C8.2, C9.2, C10.2, C11.2, C12.2, C13.2, C14.2, C15.2, C17.2, C25.2, J1.4, J2.A1 (GND), J2.A12 (GND), J2.B1 (GND), J2.B12 (GND), J3.4, J11.4, Q6.3 (E), R2.1, U3.8 (VSSA), U3.23 (VSS), U3.35 (VSS), U3.47 (VSS), Y1.2, Y1.4; also elsewhere on the board
unnamed 26: D13.1 (K), J9.1, Q6.2 (C); also elsewhere on the board
unnamed: Q6.1 (B), R54.2
unnamed: R2.2, SW1.2, U3.44 (BOOT0)
unnamed: C13.1, C14.1, FB1.1, U3.9 (VDDA)

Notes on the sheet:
1x 100uF per VDD
Analog Power Filtering
Decoupled Power
CL = 2*(CL0-Cs)=2*(10-5)pF=10pF

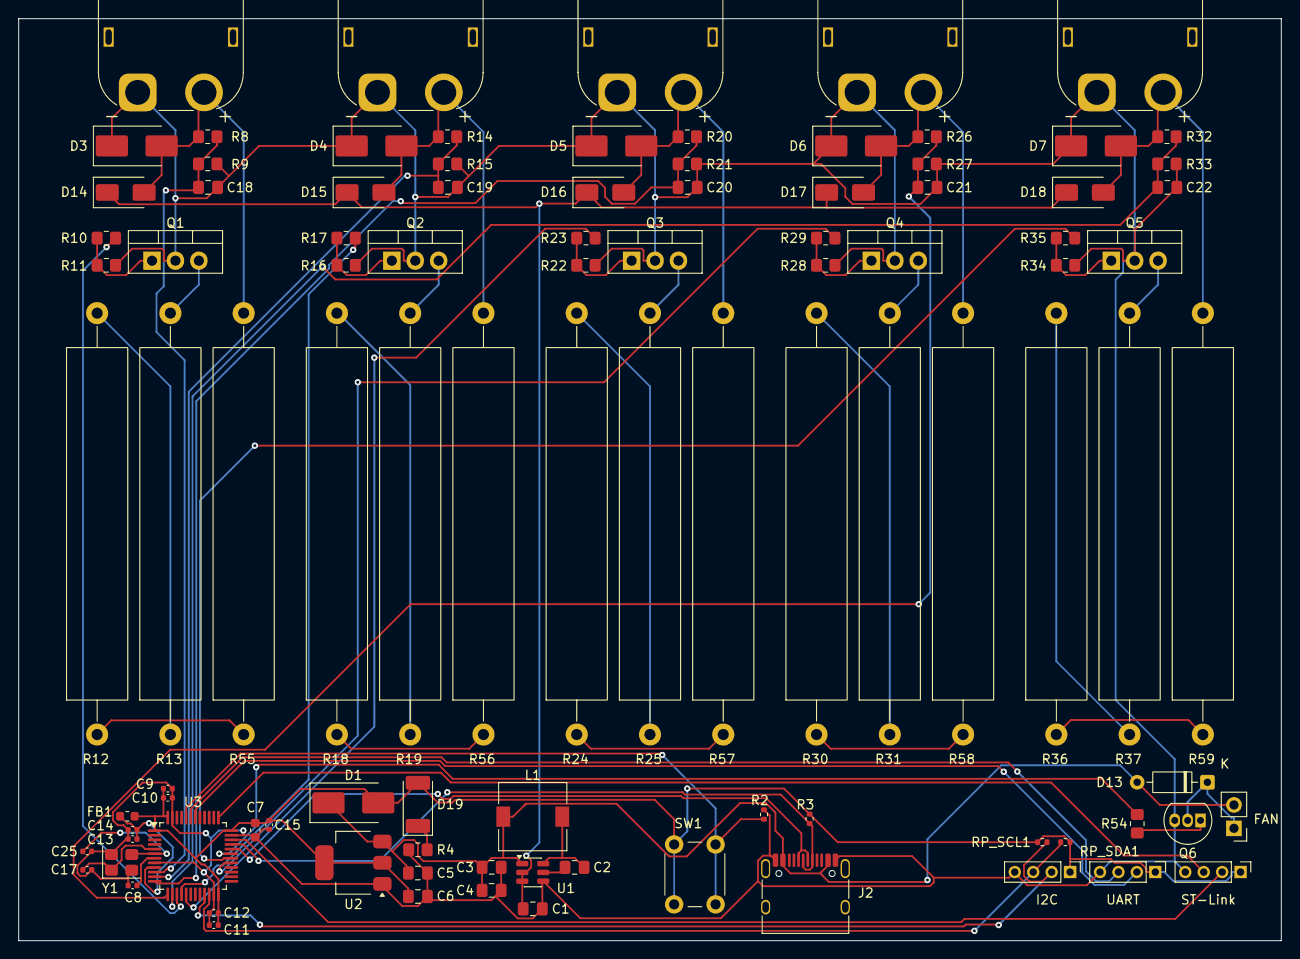
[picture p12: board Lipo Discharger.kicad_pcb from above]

Board: 2 copper layers, 137.0 x 100.0 mm, 99 parts (0 on the bottom side), 58 nets.

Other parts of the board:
FAN: FAN; PinHeader_1x02_P2.54mm_Vertical
I2C: Conn_01x04_Male; PinHeader_1x04_P2.00mm_Vertical
ST-Link: Conn_01x04_Male; PinHeader_1x04_P2.00mm_Vertical
UART: Conn_01x04_Male; PinHeader_1x04_P2.00mm_Vertical

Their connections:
+3.3V: I2C.1, ST-Link.1, UART.1; also elsewhere on the board
+5V: FAN.2; also elsewhere on the board
/STM32/I2C2_SCL: I2C.2; also elsewhere on the board
/STM32/I2C2_SDA: I2C.3; also elsewhere on the board
/STM32/SWCLK: ST-Link.3; also elsewhere on the board
/STM32/SWDIO: ST-Link.2; also elsewhere on the board
/STM32/USART1_RX: UART.3; also elsewhere on the board
/STM32/USART1_TX: UART.2; also elsewhere on the board
GND: I2C.4, ST-Link.4, UART.4; also elsewhere on the board
unnamed 26: FAN.1; also elsewhere on the board

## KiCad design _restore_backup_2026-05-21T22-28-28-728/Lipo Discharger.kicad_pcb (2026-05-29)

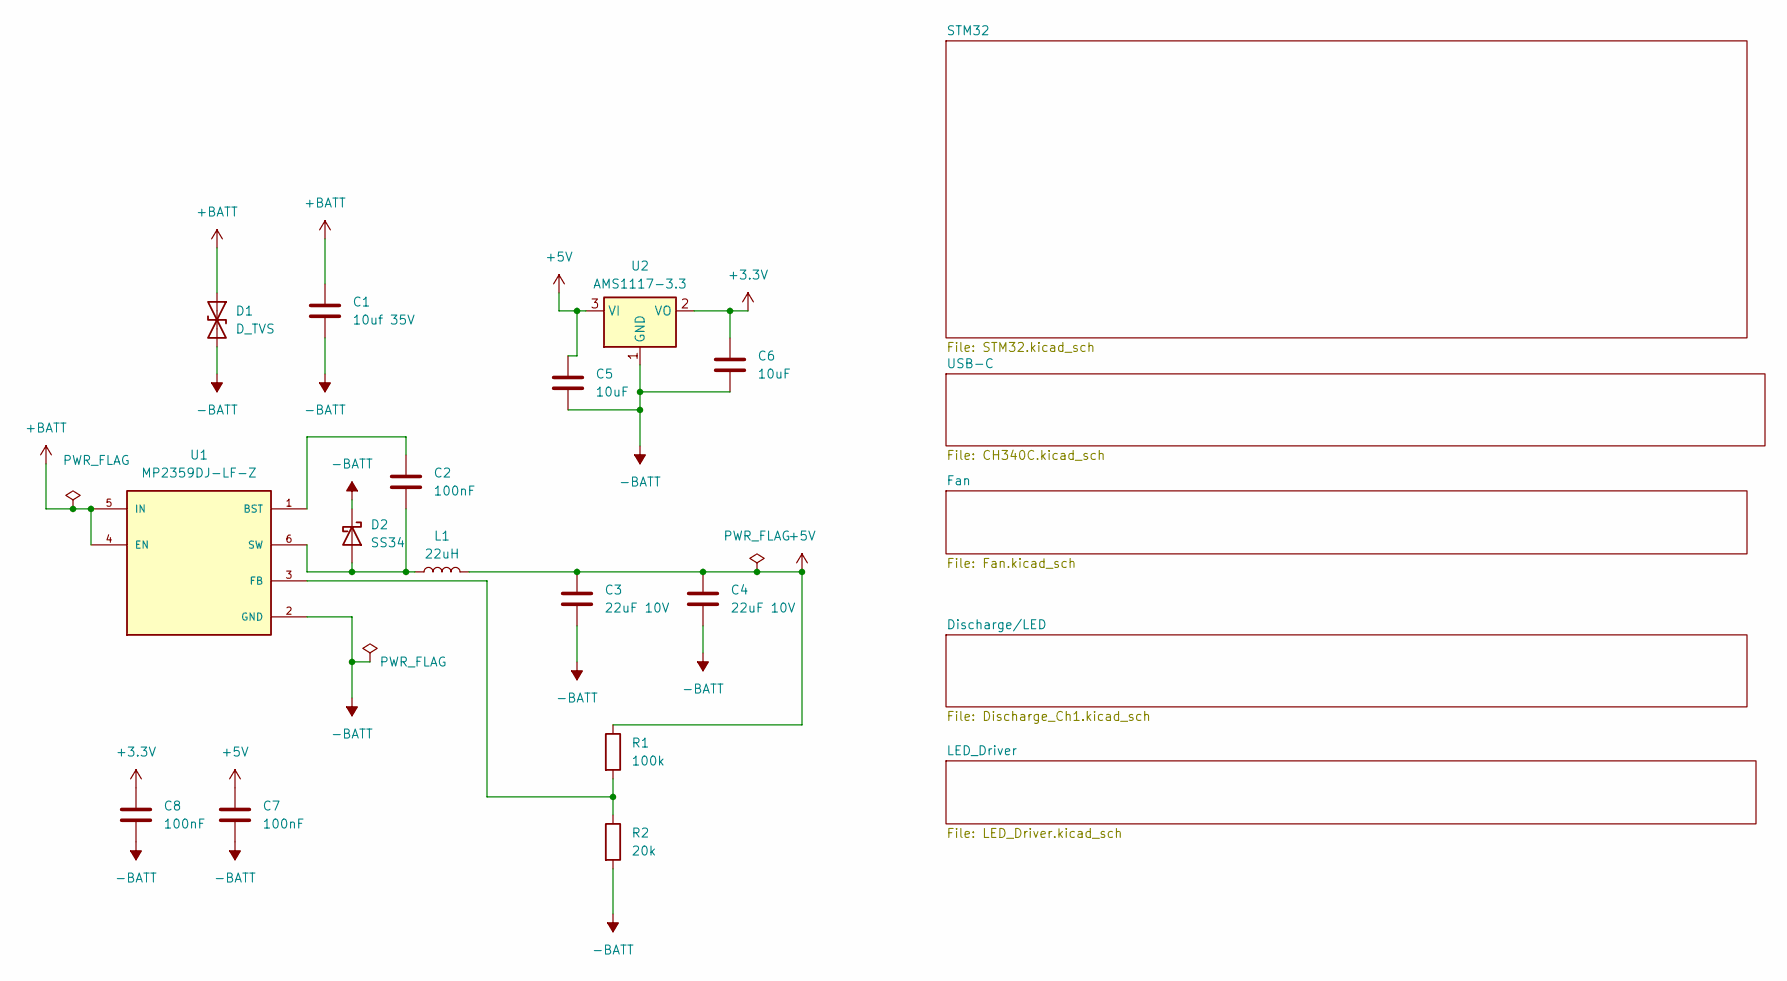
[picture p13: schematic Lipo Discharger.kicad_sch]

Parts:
C1: 10uf 35V; C_0805_2012Metric_Pad1.18x1.45mm_HandSolder
C2, C7, C8: 100nF; C_0805_2012Metric_Pad1.18x1.45mm_HandSolder
C3, C4: 22uF 10V; C_0805_2012Metric_Pad1.18x1.45mm_HandSolder
C5, C6: 10uF; C_0805_2012Metric_Pad1.18x1.45mm_HandSolder
D1: D_TVS; D_SMB_Handsoldering
D2: SS34; D_SMB_Handsoldering
L1: 22uH; L_Bourns_SRR1260
R1: 100k; R_0805_2012Metric_Pad1.20x1.40mm_HandSolder
R2: 20k; R_0805_2012Metric_Pad1.20x1.40mm_HandSolder
U1: MP2359DJ-LF-Z; TSOT-23-6_HandSoldering; PARTREV 1.21
U2: AMS1117-3.3; SOT-223-3_TabPin2

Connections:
+3.3V: C6.1, C8.1, U2.2 (VO); also elsewhere on the board
+5V: C3.1, C4.1, C5.1, C7.1, L1.2, R1.1, U2.3 (VI); also elsewhere on the board
+BATT: C1.1, D1.1 (A1), U1.4 (EN), U1.5 (IN); also elsewhere on the board
-BATT: C1.2, C3.2, C4.2, C5.2, C6.2, C7.2, C8.2, D1.2 (A2), D2.1 (K), R2.2, U1.2 (GND), U2.1 (GND); also elsewhere on the board
unnamed: C2.2, D2.2 (A), L1.1, U1.6 (SW)
unnamed: C2.1, U1.1 (BST)
unnamed: R1.2, R2.1, U1.3 (FB)

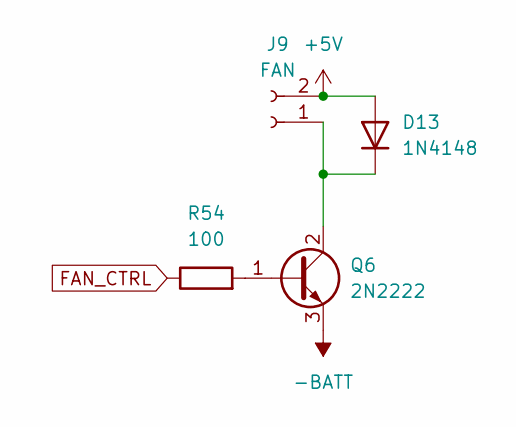
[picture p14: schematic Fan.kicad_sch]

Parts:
D13: 1N4148; D_DO-35_SOD27_P7.62mm_Horizontal
J9: FAN; PinHeader_1x02_P2.54mm_Vertical
Q6: 2N2222; TO-92_Inline
R54: 100; R_0805_2012Metric_Pad1.20x1.40mm_HandSolder

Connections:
+5V: D13.2 (A), J9.2; also elsewhere on the board
-BATT: Q6.3 (E); also elsewhere on the board
FAN_CTRL: R54.1; also elsewhere on the board
unnamed: D13.1 (K), J9.1, Q6.2 (C)
unnamed: Q6.1 (B), R54.2

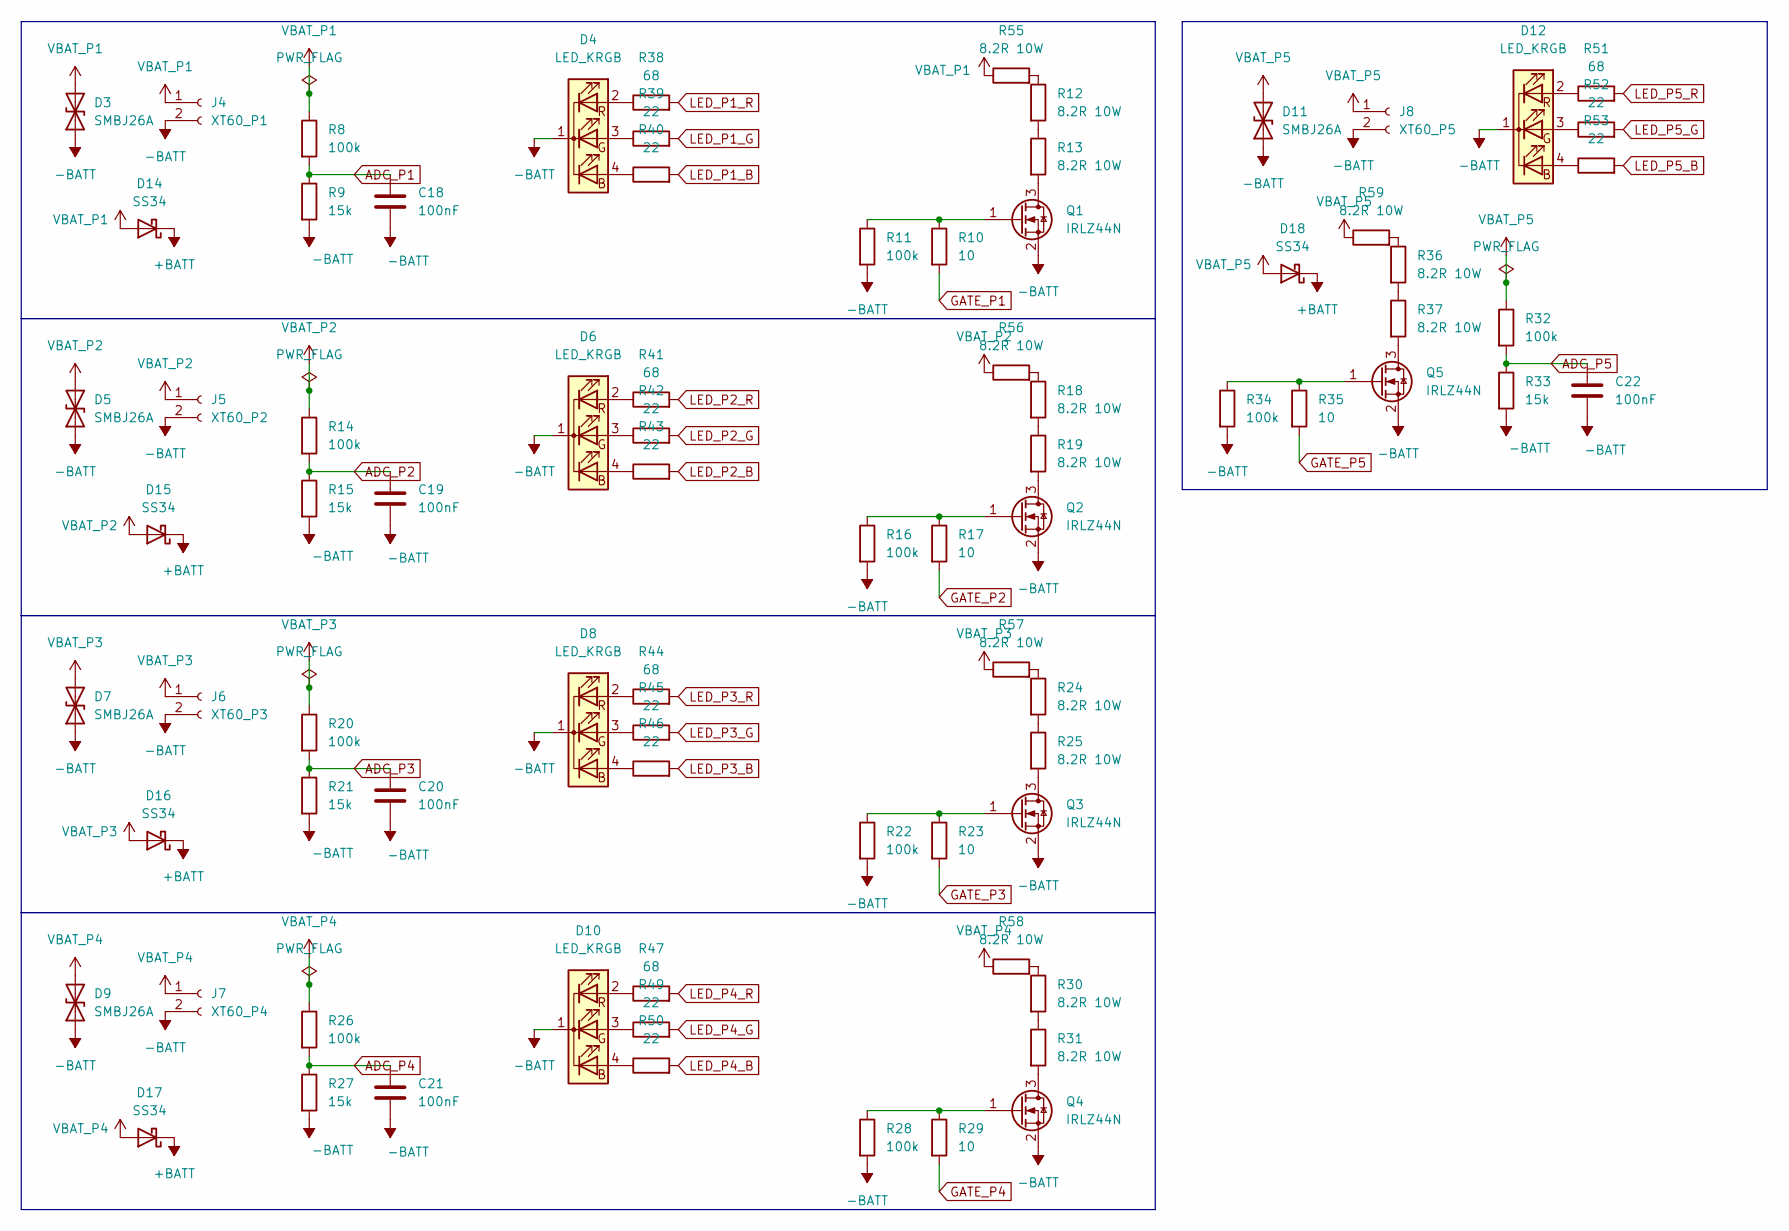
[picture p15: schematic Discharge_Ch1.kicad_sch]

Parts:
C18, C19, C20, C21, C22: 100nF; C_0805_2012Metric_Pad1.18x1.45mm_HandSolder
D3, D5, D7, D9, D11: SMBJ26A; D_SMB_Handsoldering
D4, D6, D8, D10, D12: LED_KRGB; LED_D5.0mm-4_RGB
D14, D15, D16, D17, D18: SS34; D_SMA
J4: XT60_P1; AMASS_XT60PW-M_1x02_P7.20mm_Horizontal
J5: XT60_P2; AMASS_XT60PW-M_1x02_P7.20mm_Horizontal
J6: XT60_P3; AMASS_XT60PW-M_1x02_P7.20mm_Horizontal
J7: XT60_P4; AMASS_XT60PW-M_1x02_P7.20mm_Horizontal
J8: XT60_P5; AMASS_XT60PW-M_1x02_P7.20mm_Horizontal
Q1, Q2, Q3, Q4, Q5: IRLZ44N; TO-220-3_Vertical
R8, R11, R14, R16, R20, R22, R26, R28, R32, R34: 100k; R_0805_2012Metric_Pad1.20x1.40mm_HandSolder
R9, R15, R21, R27, R33: 15k; R_0805_2012Metric_Pad1.20x1.40mm_HandSolder
R10, R17, R23, R29, R35: 10; R_0805_2012Metric_Pad1.20x1.40mm_HandSolder
R12, R13, R18, R19, R24, R25, R30, R31, R36, R37, R55, R56, R57, R58, R59: 8.2R 10W; R_Axial_Power_L25.0mm_W9.0mm_P27.94mm
R38, R41, R44, R47, R51: 68; R_0805_2012Metric_Pad1.20x1.40mm_HandSolder
R39, R40, R42, R43, R45, R46, R49, R50, R52, R53: 22; R_0805_2012Metric_Pad1.20x1.40mm_HandSolder

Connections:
+BATT: D14.1 (K), D15.1 (K), D16.1 (K), D17.1 (K), D18.1 (K); also elsewhere on the board
-BATT: C18.2, C19.2, C20.2, C21.2, C22.2, D3.1 (A1), D4.1 (K), D5.1 (A1), D6.1 (K), D7.1 (A1), D8.1 (K), D9.1 (A1), D10.1 (K), D11.1 (A1), D12.1 (K), J4.2, J5.2, J6.2, J7.2, J8.2, Q1.2 (S), Q2.2 (S), Q3.2 (S), Q4.2 (S), Q5.2 (S), R9.2, R11.2, R15.2, R16.2, R21.2, R22.2, R27.2, R28.2, R33.2, R34.2; also elsewhere on the board
ADC_P1: C18.1, R8.2, R9.1; also elsewhere on the board
ADC_P2: C19.1, R14.2, R15.1; also elsewhere on the board
ADC_P3: C20.1, R20.2, R21.1; also elsewhere on the board
ADC_P4: C21.1, R26.2, R27.1; also elsewhere on the board
ADC_P5: C22.1, R32.2, R33.1; also elsewhere on the board
GATE_P1: R10.2; also elsewhere on the board
GATE_P2: R17.2; also elsewhere on the board
GATE_P3: R23.2; also elsewhere on the board
GATE_P4: R29.2; also elsewhere on the board
GATE_P5: R35.2; also elsewhere on the board
LED_P1_B: R40.2; also elsewhere on the board
LED_P1_G: R39.2; also elsewhere on the board
LED_P1_R: R38.2; also elsewhere on the board
LED_P2_B: R43.2; also elsewhere on the board
LED_P2_G: R42.2; also elsewhere on the board
LED_P2_R: R41.2; also elsewhere on the board
LED_P3_B: R46.2; also elsewhere on the board
LED_P3_G: R45.2; also elsewhere on the board
LED_P3_R: R44.2; also elsewhere on the board
LED_P4_B: R50.2; also elsewhere on the board
LED_P4_G: R49.2; also elsewhere on the board
LED_P4_R: R47.2; also elsewhere on the board
LED_P5_B: R53.2; also elsewhere on the board
LED_P5_G: R52.2; also elsewhere on the board
LED_P5_R: R51.2; also elsewhere on the board
unnamed: D4.4 (BA), R40.1
unnamed: D4.3 (GA), R39.1
unnamed: D4.2 (RA), R38.1
unnamed: D6.4 (BA), R43.1
unnamed: D6.3 (GA), R42.1
unnamed: D6.2 (RA), R41.1
unnamed: D8.4 (BA), R46.1
unnamed: D8.3 (GA), R45.1
unnamed: D8.2 (RA), R44.1
unnamed: D10.4 (BA), R50.1
unnamed: D10.3 (GA), R49.1
unnamed: D10.2 (RA), R47.1
unnamed: D12.4 (BA), R53.1
unnamed: D12.3 (GA), R52.1
unnamed: D12.2 (RA), R51.1
unnamed: Q1.3 (D), R13.2
unnamed: Q1.1 (G), R10.1, R11.1
unnamed: Q2.3 (D), R19.2
unnamed: Q2.1 (G), R16.1, R17.1
unnamed: Q3.3 (D), R25.2
unnamed: Q3.1 (G), R22.1, R23.1
unnamed: Q4.3 (D), R31.2
unnamed: Q4.1 (G), R28.1, R29.1
unnamed: Q5.3 (D), R37.2
unnamed: Q5.1 (G), R34.1, R35.1
unnamed: R12.1, R55.2
unnamed: R12.2, R13.1
unnamed: R18.1, R56.2
unnamed: R18.2, R19.1
unnamed: R24.1, R57.2
unnamed: R24.2, R25.1
unnamed: R30.1, R58.2
unnamed: R30.2, R31.1
unnamed: R36.1, R59.2
unnamed: R36.2, R37.1
VBAT_P1: D3.2 (A2), D14.2 (A), J4.1, R8.1, R55.1
VBAT_P2: D5.2 (A2), D15.2 (A), J5.1, R14.1, R56.1
VBAT_P3: D7.2 (A2), D16.2 (A), J6.1, R20.1, R57.1
VBAT_P4: D9.2 (A2), D17.2 (A), J7.1, R26.1, R58.1
VBAT_P5: D11.2 (A2), D18.2 (A), J8.1, R32.1, R59.1

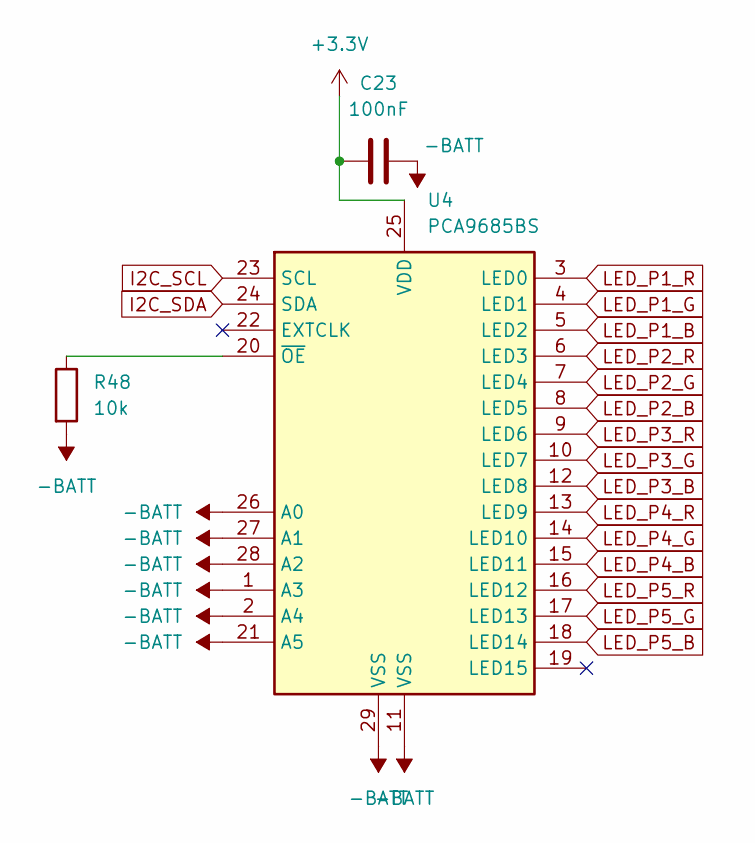
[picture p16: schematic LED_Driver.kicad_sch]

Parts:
C23: 100nF; C_0805_2012Metric_Pad1.18x1.45mm_HandSolder
R48: 10k; R_0805_2012Metric_Pad1.20x1.40mm_HandSolder
U4: PCA9685BS; TSSOP-28_4.4x9.7mm_P0.65mm

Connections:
+3.3V: C23.1, U4.25 (VDD); also elsewhere on the board
-BATT: C23.2, R48.2, U4.1 (A3), U4.2 (A4), U4.11 (VSS), U4.21 (A5), U4.26 (A0), U4.27 (A1), U4.28 (A2), U4.29 (VSS); also elsewhere on the board
I2C_SCL: U4.23 (SCL); also elsewhere on the board
I2C_SDA: U4.24 (SDA); also elsewhere on the board
LED_P1_B: U4.5 (LED2); also elsewhere on the board
LED_P1_G: U4.4 (LED1); also elsewhere on the board
LED_P1_R: U4.3 (LED0); also elsewhere on the board
LED_P2_B: U4.8 (LED5); also elsewhere on the board
LED_P2_G: U4.7 (LED4); also elsewhere on the board
LED_P2_R: U4.6 (LED3); also elsewhere on the board
LED_P3_B: U4.12 (LED8); also elsewhere on the board
LED_P3_G: U4.10 (LED7); also elsewhere on the board
LED_P3_R: U4.9 (LED6); also elsewhere on the board
LED_P4_B: U4.15 (LED11); also elsewhere on the board
LED_P4_G: U4.14 (LED10); also elsewhere on the board
LED_P4_R: U4.13 (LED9); also elsewhere on the board
LED_P5_B: U4.18 (LED14); also elsewhere on the board
LED_P5_G: U4.17 (LED13); also elsewhere on the board
LED_P5_R: U4.16 (LED12); also elsewhere on the board
unnamed: R48.1, U4.20 (~OE)

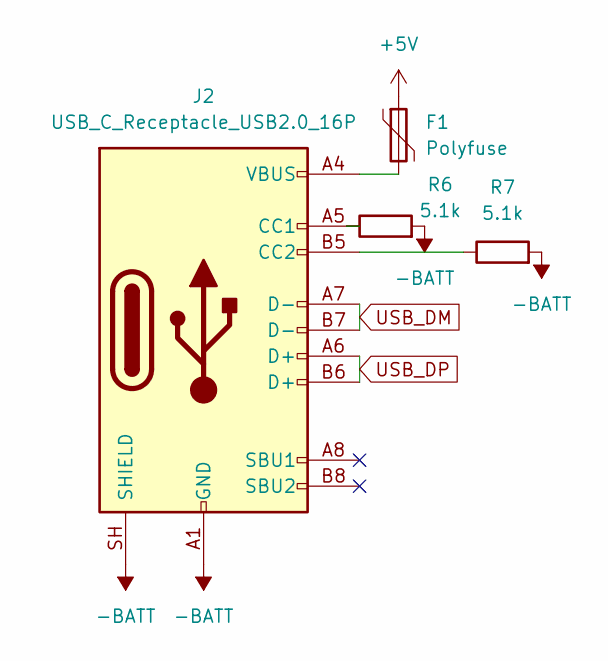
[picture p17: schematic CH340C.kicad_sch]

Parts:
F1: Polyfuse; Fuse_1206_3216Metric_Pad1.42x1.75mm_HandSolder
J2: USB_C_Receptacle_USB2.0_16P; USB_C_Receptacle_HRO_TYPE-C-31-M-12
R6, R7: 5.1k; R_0805_2012Metric_Pad1.20x1.40mm_HandSolder

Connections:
+5V: F1.1; also elsewhere on the board
-BATT: J2.A1 (GND), J2.A12 (GND), J2.B1 (GND), J2.B12 (GND), J2.SH (SHIELD), R6.2, R7.2; also elsewhere on the board
unnamed: F1.2, J2.A4 (VBUS), J2.A9 (VBUS), J2.B4 (VBUS), J2.B9 (VBUS)
unnamed: J2.A5 (CC1), R6.1
unnamed: J2.B5 (CC2), R7.1
USB_DM: J2.A7 (D-), J2.B7 (D-); also elsewhere on the board
USB_DP: J2.A6 (D+), J2.B6 (D+); also elsewhere on the board

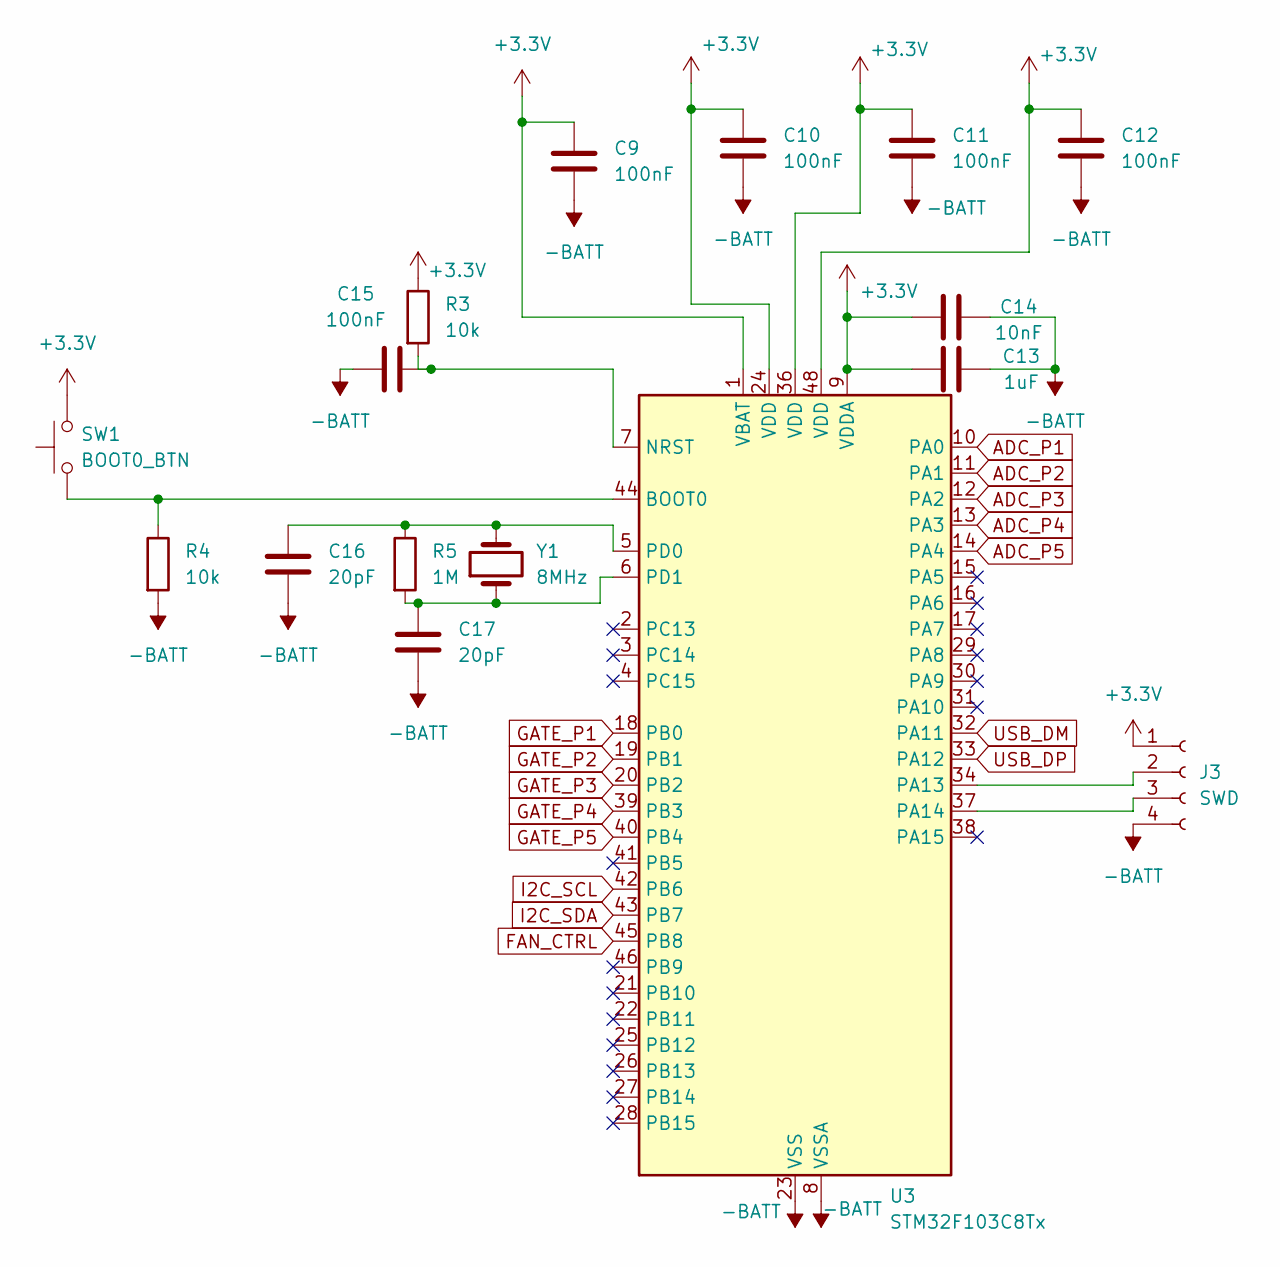
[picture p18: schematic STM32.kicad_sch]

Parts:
C9, C10, C11, C12, C15: 100nF; C_0805_2012Metric_Pad1.18x1.45mm_HandSolder
C13: 1uF; C_0805_2012Metric_Pad1.18x1.45mm_HandSolder
C14: 10nF; C_0805_2012Metric_Pad1.18x1.45mm_HandSolder
C16, C17: 20pF; C_0805_2012Metric_Pad1.18x1.45mm_HandSolder
J3: SWD; PinHeader_1x04_P2.54mm_Vertical
R3, R4: 10k; R_0805_2012Metric_Pad1.20x1.40mm_HandSolder
R5: 1M; R_0805_2012Metric_Pad1.20x1.40mm_HandSolder
SW1: BOOT0_BTN; SW_PUSH_6mm
U3: STM32F103C8Tx; LQFP-48_7x7mm_P0.5mm
Y1: 8MHz; Crystal_SMD_3225-4Pin_3.2x2.5mm_HandSoldering

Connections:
+3.3V: C9.2, C10.2, C11.2, C12.2, C13.2, C14.2, J3.1, R3.1, SW1.2, U3.1 (VBAT), U3.9 (VDDA), U3.24 (VDD), U3.36 (VDD), U3.48 (VDD); also elsewhere on the board
-BATT: C9.1, C10.1, C11.1, C12.1, C13.1, C14.1, C15.1, C16.2, C17.2, J3.4, R4.2, U3.8 (VSSA), U3.23 (VSS), U3.35 (VSS), U3.47 (VSS); also elsewhere on the board
ADC_P1: U3.10 (PA0); also elsewhere on the board
ADC_P2: U3.11 (PA1); also elsewhere on the board
ADC_P3: U3.12 (PA2); also elsewhere on the board
ADC_P4: U3.13 (PA3); also elsewhere on the board
ADC_P5: U3.14 (PA4); also elsewhere on the board
FAN_CTRL: U3.45 (PB8); also elsewhere on the board
GATE_P1: U3.18 (PB0); also elsewhere on the board
GATE_P2: U3.19 (PB1); also elsewhere on the board
GATE_P3: U3.20 (PB2); also elsewhere on the board
GATE_P4: U3.39 (PB3); also elsewhere on the board
GATE_P5: U3.40 (PB4); also elsewhere on the board
I2C_SCL: U3.42 (PB6); also elsewhere on the board
I2C_SDA: U3.43 (PB7); also elsewhere on the board
unnamed: J3.2, U3.34 (PA13)
unnamed: J3.3, U3.37 (PA14)
unnamed: R4.1, SW1.1, U3.44 (BOOT0)
unnamed: C15.2, R3.2, U3.7 (NRST)
unnamed: C16.1, R5.1, U3.5 (PD0), Y1.2
unnamed: C17.1, R5.2, U3.6 (PD1), Y1.1
USB_DM: U3.32 (PA11); also elsewhere on the board
USB_DP: U3.33 (PA12); also elsewhere on the board

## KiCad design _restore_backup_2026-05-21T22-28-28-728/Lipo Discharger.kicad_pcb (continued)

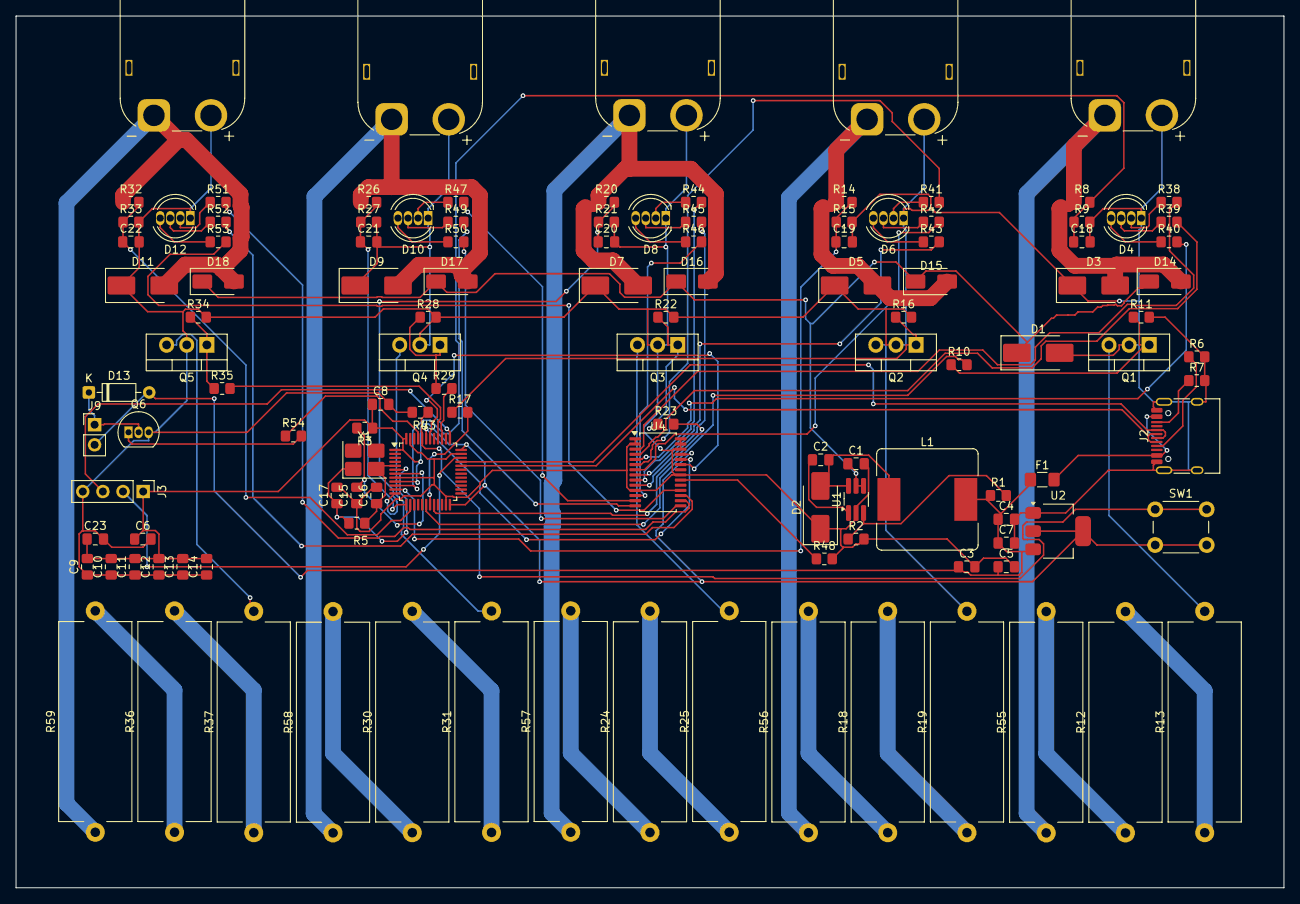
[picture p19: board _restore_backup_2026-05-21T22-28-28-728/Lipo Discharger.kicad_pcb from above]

Board: 2 copper layers, 160.0 x 110.0 mm, 122 parts (0 on the bottom side), 89 nets.

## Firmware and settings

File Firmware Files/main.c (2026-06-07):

/* =============================================================================
 * main.c — LiPo Storage Discharger
 * Target : STM32F103C8T6 @ 72MHz
 * Toolchain: STM32CubeIDE + HAL
 *
 * CubeMX peripheral configuration summary:
 *   ADC1  — Scan mode, 5 channels (IN0–IN4 = PA0–PA4), software trigger,
 *            continuous conversion OFF (we trigger manually per port)
 *   I2C1  — Standard mode 100kHz, PB6=SCL, PB7=SDA
 *   GPIO  — PB0/1/3/4/8 push-pull outputs (gates)
 *            PA5 push-pull output (fan)
 *            PA11/PA12 USB (handled by bootloader, no init needed in app)
 * =============================================================================
 */

#include "main.h"

/* ---------------------------------------------------------------------------
 * HAL handles — defined here, extern'd in main.h
 * ---------------------------------------------------------------------------*/
ADC_HandleTypeDef  hadc1;
I2C_HandleTypeDef  hi2c1;

/* ===========================================================================
 * main()
 * ===========================================================================*/
int main(void)
{
    HAL_Init();
    SystemClock_Config();   /* 72 MHz from HSE via PLL */

    MX_GPIO_Init();
    MX_ADC1_Init();
    MX_I2C1_Init();

    /* Run ADC self-calibration — mandatory on F1 for accurate readings */
    HAL_ADCEx_Calibration_Start(&hadc1);

    App_Run();   /* Never returns */
}

/* ===========================================================================
 * SystemClock_Config
 * 72 MHz: HSE 8MHz → PLL x9
 * AHB/APB2 = 72MHz, APB1 = 36MHz
 * ADC clock = PCLK2/6 = 12MHz  (max 14MHz)
 * ===========================================================================*/
void SystemClock_Config(void)
{
    RCC_OscInitTypeDef osc = {0};
    RCC_ClkInitTypeDef clk = {0};
    RCC_PeriphCLKInitTypeDef periph = {0};

    osc.OscillatorType      = RCC_OSCILLATORTYPE_HSE;
    osc.HSEState            = RCC_HSE_ON;
    osc.HSEPredivValue      = RCC_HSE_PREDIV_DIV1;
    osc.PLL.PLLState        = RCC_PLL_ON;
    osc.PLL.PLLSource       = RCC_PLLSOURCE_HSE;
    osc.PLL.PLLMUL          = RCC_PLL_MUL9;
    HAL_RCC_OscConfig(&osc);

    clk.ClockType           = RCC_CLOCKTYPE_HCLK | RCC_CLOCKTYPE_SYSCLK
                            | RCC_CLOCKTYPE_PCLK1 | RCC_CLOCKTYPE_PCLK2;
    clk.SYSCLKSource        = RCC_SYSCLKSOURCE_PLLCLK;
    clk.AHBCLKDivider       = RCC_SYSCLK_DIV1;
    clk.APB1CLKDivider      = RCC_HCLK_DIV2;   /* 36 MHz max for APB1 */
    clk.APB2CLKDivider      = RCC_HCLK_DIV1;   /* 72 MHz */
    HAL_RCC_ClockConfig(&clk, FLASH_LATENCY_2);

    periph.PeriphClockSelection = RCC_PERIPHCLK_ADC;
    periph.AdcClockSelection    = RCC_ADCPCLK2_DIV6;   /* 12 MHz */
    HAL_RCCEx_PeriphCLKConfig(&periph);
}

/* ===========================================================================
 * MX_GPIO_Init
 * Gate outputs: PB0, PB1, PB3, PB4, PB8 — push-pull, default LOW
 * Fan output:   PA5                       — push-pull, default LOW
 * ADC inputs:   PA0–PA4 are configured as analog by MX_ADC1_Init
 * ===========================================================================*/
static void MX_GPIO_Init(void)
{
    GPIO_InitTypeDef gpio = {0};

    __HAL_RCC_GPIOA_CLK_ENABLE();
    __HAL_RCC_GPIOB_CLK_ENABLE();

    /* --- Gate outputs on GPIOB --- */
    HAL_GPIO_WritePin(GATE_PORT,
                      GATE1_PIN | GATE2_PIN | GATE3_PIN | GATE4_PIN | GATE5_PIN,
                      GPIO_PIN_RESET);

    gpio.Pin   = GATE1_PIN | GATE2_PIN | GATE3_PIN | GATE4_PIN | GATE5_PIN;
    gpio.Mode  = GPIO_MODE_OUTPUT_PP;
    gpio.Speed = GPIO_SPEED_FREQ_LOW;
    gpio.Pull  = GPIO_NOPULL;
    HAL_GPIO_Init(GATE_PORT, &gpio);

    /* --- Fan output on GPIOA --- */
    HAL_GPIO_WritePin(FAN_PORT, FAN_PIN, GPIO_PIN_RESET);

    gpio.Pin   = FAN_PIN;
    gpio.Mode  = GPIO_MODE_OUTPUT_PP;
    gpio.Speed = GPIO_SPEED_FREQ_LOW;
    gpio.Pull  = GPIO_NOPULL;
    HAL_GPIO_Init(FAN_PORT, &gpio);
}

/* ===========================================================================
 * MX_ADC1_Init
 * Scan mode OFF — we convert one channel at a time per port.
 * Channels IN0–IN4 (PA0–PA4).
 * We reconfigure the channel rank before each conversion in app.c.
 * ===========================================================================*/
static void MX_ADC1_Init(void)
{
    __HAL_RCC_ADC1_CLK_ENABLE();
    __HAL_RCC_GPIOA_CLK_ENABLE();

    /* Configure PA0–PA4 as analog inputs */
    GPIO_InitTypeDef gpio = {0};
    gpio.Pin  = GPIO_PIN_0 | GPIO_PIN_1 | GPIO_PIN_2 | GPIO_PIN_3 | GPIO_PIN_4;
    gpio.Mode = GPIO_MODE_ANALOG;
    HAL_GPIO_Init(GPIOA, &gpio);

    hadc1.Instance                   = ADC1;
    hadc1.Init.ScanConvMode          = ADC_SCAN_DISABLE;  /* Single channel per call */
    hadc1.Init.ContinuousConvMode    = DISABLE;
    hadc1.Init.DiscontinuousConvMode = DISABLE;
    hadc1.Init.ExternalTrigConv      = ADC_SOFTWARE_START;
    hadc1.Init.DataAlign             = ADC_DATAALIGN_RIGHT;
    hadc1.Init.NbrOfConversion       = 1;
    HAL_ADC_Init(&hadc1);
}

/* ===========================================================================
 * MX_I2C1_Init
 * Standard mode, 100 kHz, PB6=SCL, PB7=SDA
 * ===========================================================================*/
static void MX_I2C1_Init(void)
{
    __HAL_RCC_I2C1_CLK_ENABLE();
    __HAL_RCC_GPIOB_CLK_ENABLE();

    /* PB6 SCL, PB7 SDA — alternate function open-drain */
    GPIO_InitTypeDef gpio = {0};
    gpio.Pin   = GPIO_PIN_6 | GPIO_PIN_7;
    gpio.Mode  = GPIO_MODE_AF_OD;
    gpio.Speed = GPIO_SPEED_FREQ_HIGH;
    HAL_GPIO_Init(GPIOB, &gpio);

    hi2c1.Instance             = I2C1;
    hi2c1.Init.ClockSpeed      = 100000;
    hi2c1.Init.DutyCycle       = I2C_DUTYCYCLE_2;
    hi2c1.Init.OwnAddress1     = 0;
    hi2c1.Init.AddressingMode  = I2C_ADDRESSINGMODE_7BIT;
    hi2c1.Init.DualAddressMode = I2C_DUALADDRESS_DISABLE;
    hi2c1.Init.GeneralCallMode = I2C_GENERALCALL_DISABLE;
    hi2c1.Init.NoStretchMode   = I2C_NOSTRETCH_DISABLE;
    HAL_I2C_Init(&hi2c1);
}

/* ===========================================================================
 * HAL_MspInit — called by HAL_Init()
 * ===========================================================================*/
void HAL_MspInit(void)
{
    __HAL_RCC_AFIO_CLK_ENABLE();
    __HAL_RCC_PWR_CLK_ENABLE();

    /* Disable JTAG, keep SWD — frees PB3, PB4 for GPIO use as gate pins */
    __HAL_AFIO_REMAP_SWJ_NOJTAG();
}

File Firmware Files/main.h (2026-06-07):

/* =============================================================================
 * main.h — LiPo Storage Discharger
 * Target : STM32F103C8T6 @ 72MHz
 * =============================================================================
 */
#ifndef __MAIN_H
#define __MAIN_H

#ifdef __cplusplus
extern "C" {
#endif

#include "stm32f1xx_hal.h"
#include <stdint.h>
#include <stdbool.h>

/* ---------------------------------------------------------------------------
 * HAL peripheral handles
 * Defined in main.c, referenced everywhere else via extern.
 * ---------------------------------------------------------------------------*/
extern ADC_HandleTypeDef  hadc1;
extern I2C_HandleTypeDef  hi2c1;

/* ---------------------------------------------------------------------------
 * Gate pins  (all on GPIOB)
 * PB0, PB1, PB3, PB4, PB8
 * ---------------------------------------------------------------------------*/
#define GATE_PORT           GPIOB
#define GATE1_PIN           GPIO_PIN_0
#define GATE2_PIN           GPIO_PIN_1
#define GATE3_PIN           GPIO_PIN_3
#define GATE4_PIN           GPIO_PIN_4
#define GATE5_PIN           GPIO_PIN_8

/* ---------------------------------------------------------------------------
 * Fan  (PA5)
 * ---------------------------------------------------------------------------*/
#define FAN_PORT            GPIOA
#define FAN_PIN             GPIO_PIN_5

/* ---------------------------------------------------------------------------
 * PCA9685  (I2C1 on PB6/PB7)
 * ---------------------------------------------------------------------------*/
#define PCA9685_I2C_ADDR    (0x40 << 1)   /* HAL 8-bit format */
#define PCA9685_PWM_FREQ    1000           /* Hz */

/* ---------------------------------------------------------------------------
 * Application entry point (called from main() after MX_ inits)
 * ---------------------------------------------------------------------------*/
void App_Run(void);

/* ---------------------------------------------------------------------------
 * CubeMX-style init prototypes (defined in main.c)
 * ---------------------------------------------------------------------------*/
void SystemClock_Config(void);
static void MX_GPIO_Init(void);
static void MX_ADC1_Init(void);
static void MX_I2C1_Init(void);

#ifdef __cplusplus
}
#endif
#endif /* __MAIN_H */

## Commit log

2026-05-29 Initial commit - Lipo storage discharger PCB
2026-05-29 Renamed Files
    [Lipo Discharger-B_Cu.gbr, Lipo Discharger-B_Mask.gbr, Lipo Discharger-B_Paste.gbr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]
2026-06-07 Complete board redesign
    [AssemblyV1.0.0.3mf, AssemblyV1.0.0.SLDASM, Base^Case_AssemblyV1.0.0.3mf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]
2026-06-11 Before autorouting backup
    [Lipo Discharger.kicad_pcb, autorouter_v34.dsn]
2026-06-17 Document problems with current lipo discharging solutions
    Added section on problems with current lipo discharging solutions, detailing shortcomings and issues.
2026-06-17 Document issues with existing lipo charging solutions
    Added a section discussing problems with current lipo charger and discharger solutions.
2026-06-17 V0.2.0 after sending to manufacturing
    [Lipo Discharger-B_Cu.gbr, Lipo Discharger-B_Mask.gbr, Lipo Discharger-B_Paste.gbr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]
2026-06-17 Added BOM to add to release
    [Lipo Discharger v0.2.0 BOM.csv]
